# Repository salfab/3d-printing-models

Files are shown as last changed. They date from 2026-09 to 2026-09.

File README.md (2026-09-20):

# 3d-printing-models

Pièces paramétriques modélisées en [OpenSCAD](https://openscad.org/), destinées à
l'impression 3D. Un modèle par sous-répertoire, avec son outillage de rendu, de coupe et
de dessin technique.

Unités : millimètres. Documentation en français.

**[Méthode de conception](WORKFLOW.md)** — le cycle de travail, la discipline de
vérification et les pièges rencontrés, avec leurs chiffres.

**[Journal de conception](work-log/)** — les sessions racontées, ce qu'on y a appris et
ce qu'on y a raté.

## Modèles

| Modèle | Description |
|---|---|
| [rack-sodastream](models/rack-sodastream/) | Rack à visser sous une planche pour deux cylindres de CO2 SodaStream, tenus à l'horizontale et invisibles depuis le dessus |

## Démarrer

Il faut OpenSCAD et Python 3.11 ou plus.

```bash
winget install OpenSCAD.OpenSCAD
```

```bash
python scripts/setup_libs.py
```

Le second installe les bibliothèques OpenSCAD tierces dans `vendor/`, qui est exclu du
dépôt.

## Outillage

`scripts/scad.py` pilote OpenSCAD : il gère les caméras, les fichiers d'enrobage et les
sorties, qui atterrissent toutes dans `models/<slug>/out/`.

```bash
python scripts/scad.py views   <slug>                    # rendus 3D : iso, face, droite, dessus
python scripts/scad.py section <slug> --axis x --at 0    # coupe en demi-espace
python scripts/scad.py slices  <slug> --axis z --count 5 # tranches 2D
python scripts/scad.py drawing <slug>                    # dessins techniques (SVG + PNG)
python scripts/scad.py info    <slug>                    # encombrement, lu dans le maillage
python scripts/scad.py stl     <slug> --binaire          # export STL
```

`--fast` bascule en aperçu au lieu du rendu complet : quelques dixièmes de seconde au
lieu de plusieurs minutes, pour itérer sur la forme.

`info` et les commandes de tranche lisent le **maillage exporté**, pas le source. Les
cotes rapportées sont donc celles qui partiront à l'impression, polygonisation comprise.

## Structure

```
models/<slug>/
  <slug>.scad     fichier principal, exposant un module main()
  README.md       à quoi sert la pièce, cotes, montage, impression
  out/            tout le généré — régénérable, hors dépôt
lib/std.scad      coupes, tranches, vues techniques
scripts/          outillage
vendor/           bibliothèques tierces — hors dépôt
```

Chaque modèle expose un `module main()` et l'appelle : l'outillage fait `use <…>` sur le
fichier, et les rendus, coupes et dessins en dépendent.

## Licence

Aucune licence n'est encore fixée pour ce dépôt. `vendor/BOSL2`, installé séparément,
reste sous sa propre licence BSD-2-Clause.

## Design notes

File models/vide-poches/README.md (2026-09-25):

# vide-poches

Panier mural qui s'enfile par le haut sur deux vis à tête fraisée, en les gardant
invisibles. Fond à deux niveaux reliés par un galbe, crochet à casque sous la partie
haute, inserts amovibles qui bordent l'ouverture d'un liseré — de la couleur qu'on
veut.

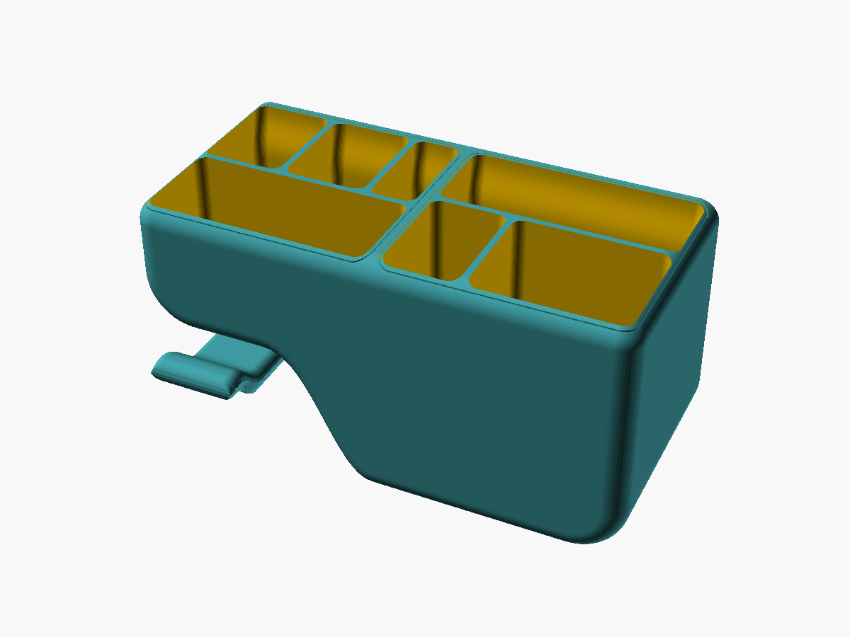
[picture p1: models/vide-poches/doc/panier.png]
Le panier, inserts en place


| Le dos, côté mur | Les inserts, vus de dessus | De profil |
|---|---|---|
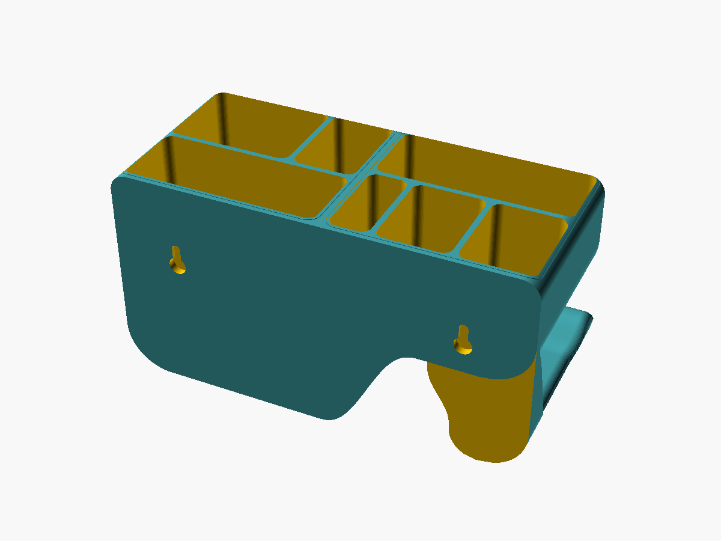
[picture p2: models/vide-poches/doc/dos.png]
Dos et trous de serrure
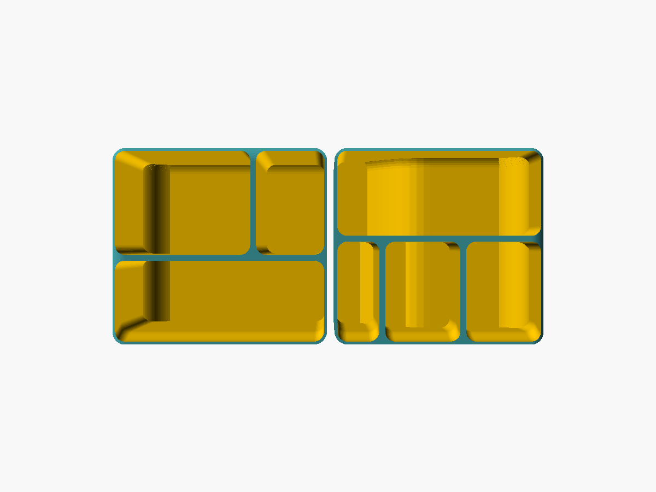
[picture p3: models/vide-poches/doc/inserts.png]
Inserts
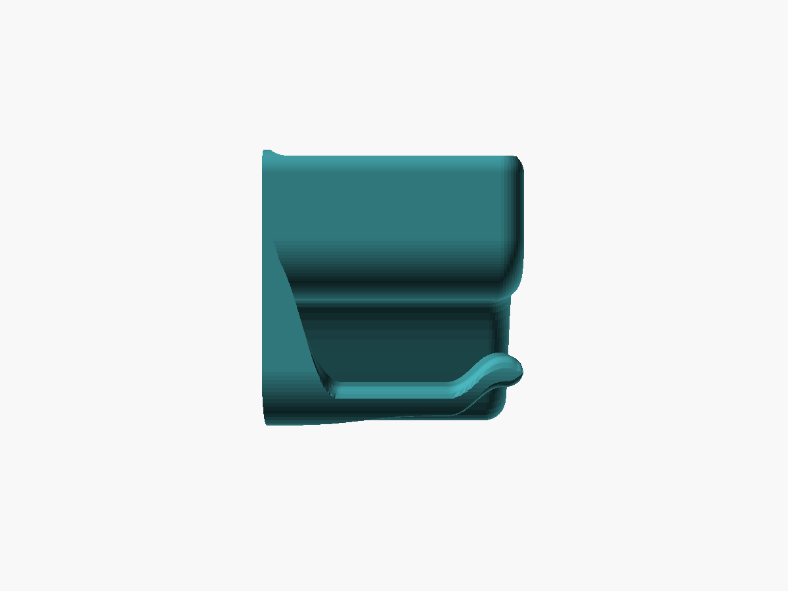
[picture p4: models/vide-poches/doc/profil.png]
Profil et crochet
|  |  |  |
| deux trous de serrure, renflements cachés dans le bac | sept compartiments, deux corps | le crochet prolonge le dessous en S |

### Voir le modèle en 3D

GitHub affiche les fichiers `.stl` dans un **viewer 3D interactif** — clic-glisser pour
tourner, molette pour zoomer, et un bouton pour les télécharger :

- **[Coque](stl/vide-poches-coque.stl)** — 181 × 84,9 × 95 mm
- **[Inserts](stl/vide-poches-insert.stl)** — deux corps, 175,6 × 79,9 × 91,9 mm
- **[Gabarit de pose](stl/vide-poches-gabarit.stl)** — 189 × 28 × 4,8 mm
- **[Pièce d'essai](stl/vide-poches-essai.stl)** — les 10 derniers mm de la coque et des inserts

## 1. À quoi sert la pièce

Vider ses poches en rentrant — paquet de tabac, briquets, lunettes, câbles USB,
petites bricoles — et suspendre dessous un casque **Sony WH-1000XM5**, qui pèse 250 g
et ne se plie pas.

Elle s'accroche sur le flanc d'un meuble en bois, à deux vis **SPAX 3 × 12 à tête
fraisée** posées pour elle, à 124 mm l'une de l'autre. Relevé au pied à coulisse :
tête Ø 6, tige Ø 3, fraisure à 90° (cône de 1,5 mm) ; le petit bord cylindrique
au-dessus est estimé à 0,2.

La forme tient à trois choix :

- **Tout se range debout.** Les lunettes pliées passent de 150 × 46 au sol à 55 × 42,
  la poche à tabac de 105 × 30 à 85 × 30.
- **Le fond est à deux niveaux.** Un bac uniformément profond serait un puits où
  pêcher un briquet : il plonge à gauche (90 mm utiles pour ce qui tient debout) et
  remonte à droite (44 mm pour le vrac), par un galbe et non une marche.
- **Les vis sont invisibles.** La tête entre par un trou au bas de la course ; on
  pousse contre le bois et on descend de 8 mm, et elle se retrouve captive derrière
  une peau de 1,2 mm. Les renflements qui l'entourent sont sous l'arase, derrière
  les inserts.

## 2. Pièces à imprimer

| Pièce | `PIECE=` | Qté | Rôle |
|---|---|---|---|
| Coque | `coque` | 1 | dos, bac à deux niveaux, crochet |
| Inserts | `insert` | 1 jeu | deux petits bacs à séparations, un par zone — **deux corps** dans un même STL |
| Gabarit | `gabarit` | 1 | réglet à trou de serrure, repère de perçage, cale de profondeur — consommable |
| Pièce d'essai | `essai` | 1 | valide le jeu insert / coque **avant tout** |

```bash
python scripts/scad.py stl vide-poches -D PIECE=coque   --binaire
python scripts/scad.py stl vide-poches -D PIECE=insert  --binaire
python scripts/scad.py stl vide-poches -D PIECE=gabarit --binaire
python scripts/scad.py stl vide-poches -D PIECE=essai   --binaire
```

**Deux couleurs de PLA** : les inserts portent le liseré qui borde l'ouverture, et
dessinent dans une autre couleur un filet tout autour du bord, plus les séparations.

Coque et inserts se déduisent de la **même liste `cuves`** : un compartiment ajouté
ou déplacé met tout à jour.

## 3. Cotes principales

Mesurées sur les maillages exportés (moteur Manifold ; `--cgal` rend le même volume
au dixième de cm³).

| Pièce | Volume | Encombrement |
|---|---|---|
| Coque | 184,8 cm³ | 181,0 × 84,9 × 95,0 mm |
| Inserts (2 corps) | 143,0 cm³ (74,2 + 68,8) | 175,6 × 79,9 × 91,9 mm |
| Gabarit | 14,4 cm³ | 189 × 28 × 4,8 mm |

**Compartiments** — cotes utiles, entre parois d'insert :

| Objet | Largeur × profondeur | Hauteur utile | Pourquoi |
|---|---|---|---|
| Poche à tabac, debout | 85,0 × 30,0 | 90 | c'est elle qui fixe la largeur de la zone profonde |
| Lunettes, debout | **55,0** × 41,8 | 90 | à 50, les branches d'une monture large forçaient |
| Stylos, grands objets | 27,6 × 41,8 | 90 | ce qui reste de la zone profonde |
| Briquets, debout | 17,0 × 37,2 | 65 à 76 | Bic J26 et Clipper (16 d'épaisseur) ; replat à 76 |
| Câbles USB | 30,5 × 37,2 | 44 à 47 | replat à 47 : le galbe y montait à 60° contre la paroi |
| Petits objets | 30,5 × 37,2 | 44 | sur le plat |
| Petites bricoles | 82,8 × 34,6 | 44 à 70 | replat à 70 : sans lui, un puits de 90 côté cloison |

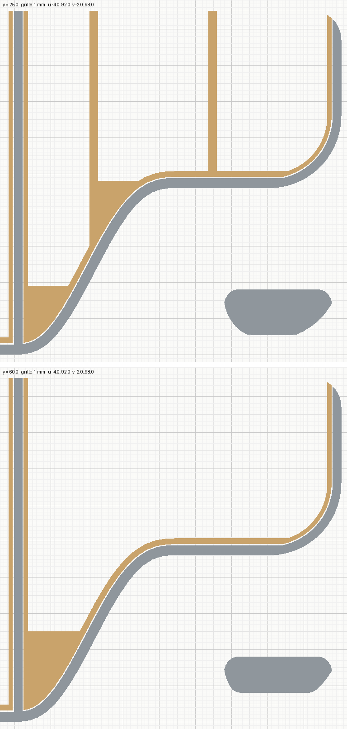
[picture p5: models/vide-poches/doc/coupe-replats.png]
Coupes au droit des câbles et des bricoles


*Coupes en travers, coque en gris, inserts en ocre. En haut au droit des câbles
(y = 25), en bas au droit des bricoles (y = 60) : sous chaque replat, l'insert est
plein jusqu'au galbe, et le compartiment repose sur la coque.*

**Fixation** — de l'arrière vers l'avant, au droit de chaque vis :

```
bois | 1,6 de tige libre | fraisage : 1,0 dans la plaque | 0,4 de cône + 0,2 de bord | 0,4 de jeu | peau 1,2
     └──────────── plaque porteuse 2,6 ────────────┘└───────────── logement 1,0 ─────────────┘
```

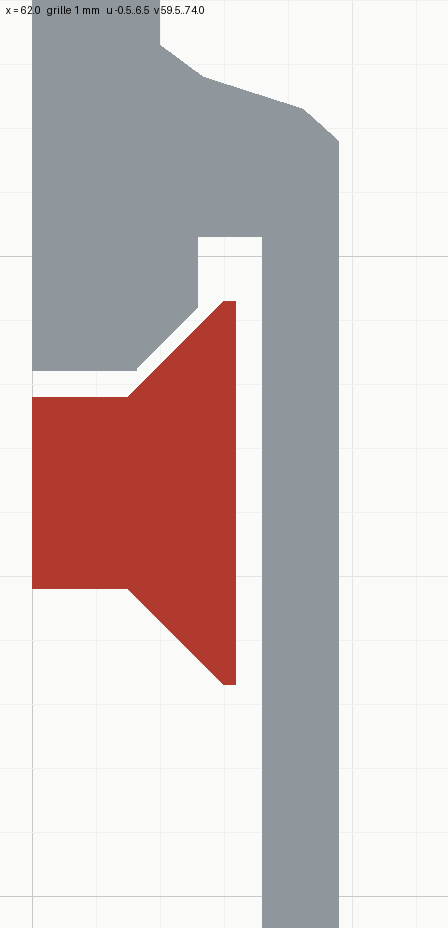
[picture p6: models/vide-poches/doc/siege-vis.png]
La vis dans son siège, en coupe


*Coupe dans l'axe d'une vis (rouge) : la plaque porteuse est fraisée au cône de la
tête, avec 0,3 mm de jeu au rayon.*

| Cote | Valeur | Pourquoi |
|---|---|---|
| Dos, hors fixation | 2,0 mm | `dos_ep` — plein, le trancheur fait l'allègement |
| Dos au droit des vis | 4,8 mm | `dos_e` = plaque + logement + peau |
| Plaque porteuse | 2,6 mm | elle mord 1,0 mm dans le cône : la tête porte sur 19 mm² et s'y centre |
| Jeu au fraisage | 0,3 mm | `jeu_cone` — au rayon, donc aussi en axial à 45° ; 0,4 avec la cale de 1,8 |
| Peau avant | 1,2 mm | `dos_av` — trois passes de buse, elle ne porte rien |
| Course d'enfilage | 8 mm | `course` = rayon du trou d'entrée + rayon de la tête + 1 mm d'appui |
| Trou d'entrée / logement | Ø 7,5 / Ø 8,0 | le logement doit rester **plus large** que le trou qu'il prolonge |
| Axe des vis | 29 mm sous l'arase | au plus bas : le renflement droit se pose à 2 mm du fond peu profond |
| Entraxe | 124 mm | le renflement s'éteint 18 mm avant la paroi latérale, sans la toucher |

**Bac et inserts :**

| Cote | Valeur | Pourquoi |
|---|---|---|
| Parois / cloison / fond | 2,4 / 2,4 / 2,8 mm | `fond` ≠ `paroi`, sinon deux surfaces confondues (§6) |
| Marche entre les niveaux | 46 mm sur 45 de galbe | S quintique : rayon concave mini 17 mm, contre 7 en cubique |
| Arrondi de la face avant et des angles hauts | 8 mm | les deux rayons égaux, sinon angle vif sur la face avant |
| Jeu insert / coque | 0,3 mm par côté | `insert_jeu` — c'est aussi le filet entre les couleurs ; à valider sur `essai` |
| Paroi d'insert | 1,2 mm | trois périmètres ; elle porte le liseré |
| Paroi arrière d'insert | S de 5,1 à 2,3 mm du mur | passe devant les renflements puis recule : liseré de même largeur partout, 14° au plus fort |

**Crochet :**

| Cote | Valeur | Pourquoi |
|---|---|---|
| Portée | 84 mm | le bout arrive à 0,9 de la face avant |
| Creux de l'arceau | ~50 mm, 33 de fond plat | c'est ce creux qui fait que la sangle s'assoit au lieu de se percher |
| Passage sous la coque | 28 mm | la sangle et son coussin |
| Bras au plus fin | 10 mm | 0,3 MPa sous 250 g, contre ~20 MPa de cohésion entre couches |
| Butée | 10 mm, spatule relevée sur 20 | 43° au plus : imprimable sans support |
| Arrondi des arêtes | 4 mm, dessus et dessous | 40 % de l'épaisseur du bras |

Le crochet vu de face reprend la vague de la coque (flanc droit dans le prolongement,
coin de 20, flanc gauche en S) ; de côté, sa racine part tangente au dessous du panier.

## 4. Montage

L'ordre compte : le gabarit se pose sur la **première** vis, et c'est de là qu'il
reporte la seconde.

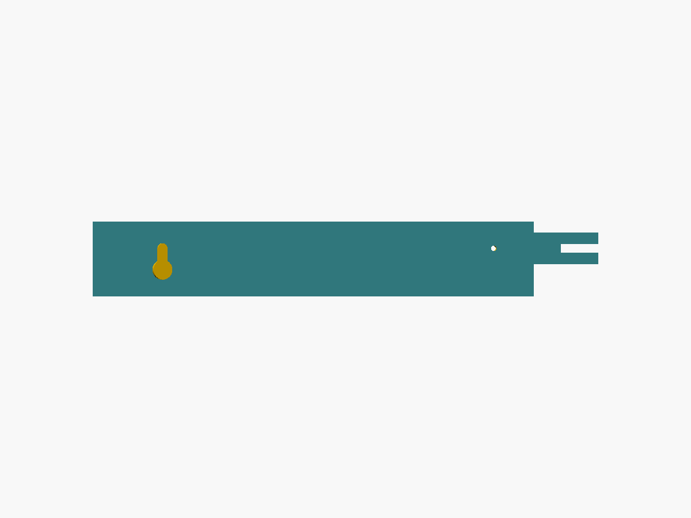
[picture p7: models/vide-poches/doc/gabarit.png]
Le gabarit, vu de dessous


*Le gabarit vu côté mur : à gauche le trou de serrure, identique à celui du panier ;
à droite le repère de Ø 2 et la cale en fourche.*

0. **Imprimer d'abord le gabarit et la pièce d'essai.** L'anneau d'insert doit
   entrer dans l'anneau de coque sans forcer ni ballotter ; sinon, ajuster
   `insert_jeu`.
1. **Poser la première vis** là où le panier doit venir (avant-trou Ø 2 en bois
   tendre, Ø 2,5 en dur). C'est elle qui fixe la hauteur.
2. **Régler sa profondeur à la cale** : glisser la fourche sous la tête, à plat
   contre le bois, et visser jusqu'à ce que le cône en pince les bords. Elle se
   retire en forçant légèrement ; la tige libre fait 1,6 mm.
3. **Enfiler le gabarit** sur cette vis par son trou de serrure : présenter, pousser,
   descendre de 8 mm. Il doit être **captif**. S'il force, la vis est trop profonde ;
   s'il flotte, pas assez. **Si le gabarit ne s'enfile pas, le panier non plus.**
4. **Le mettre d'aplomb et marquer** à travers le repère. Rien sur la pièce ne
   garantit l'horizontale : un petit niveau, ou une mesure égale depuis le chant du
   meuble. Deux vis à des hauteurs différentes font vriller le panier.
5. **Percer, visser la seconde vis**, et la régler à la même cale.
6. **Présenter la coque** les têtes en face des trous d'entrée, **pousser** contre
   le bois, **descendre de 8 mm** : elle vient en butée seule.
7. **Poser les deux inserts**, chacun dans sa zone, à la verticale.

Pour décrocher : remonter de 8 mm, tirer vers soi.

## 5. Impression

- **Coque couchée sur son dos.** La direction de construction est la profondeur : la
  silhouette de la façade sort sans support, et toute surface tournée vers l'avant
  est un toit qui se pose sur la couche du dessous. Seul l'arrière est contraint, et
  il est plat.
- **Inserts à plat, fond contre le plateau.** Seul support du projet : sous le fond de
  l'insert peu profond, qui suit le galbe (~40 g, face cachée).
- **Gabarit à plat**, dans la même orientation que la coque : le pontage de sa peau
  est représentatif de celui du panier.
- **PLA**, remplissage libre : aucune cavité fermée dans aucune pièce.
- Emprise : 181 × 95 mm pour la coque ; 181 × 176 pour la pièce d'essai.

## 6. Contraintes à connaître avant de modifier

**Fixation**

- **Le fraisage ne tolère l'erreur que dans un sens.** Vis trop profonde : la plaque
  ne passe plus. Pas assez : un peu plus de jeu. D'où la cale de **1,8** et non 1,7 —
  1,7 n'est pas un multiple de la couche de 0,2, et le cône écrase le PLA en pinçant ;
  les deux poussent du côté qui coince. Chaque dixième de fourche est un dixième de
  profondeur de vis.
- **Le fraisage doit épouser le cône.** Un chanfrein parallèle mais décalé au rayon
  ne le touche jamais — la tête n'appuie qu'après que le panier a avancé d'autant.
  Vérifier en plaçant la vraie vis dans le canal.
- **`porteur` < fin du cône**, sinon la plaque bute sur le bord cylindrique de la tête.
  Assertion.
- **Le logement de tête reste plus large que le trou d'entrée**, et le fraisage se
  prolonge de 0,3 mm dans le logement : à égalité ou à fleur, les contours coïncident
  (116 arêtes non-variété). Assertions.
- **`z_vis` se déduit du fond, par le bas.** Plus haut, le S de la paroi arrière de
  l'insert se raccourcit ; il faut 10 mm libres au-dessus des renflements. Assertion.
- **Le renflement est ajouté après le creusement du bac**, sinon il disparaît avec lui.
  Il reste sous l'arase (assertion) et au-dessus du fond peu profond (assertion).

**Bac et inserts**

- **Les cavités sont découpées dans l'enveloppe intérieure**, jamais posées à un
  niveau : le dessous remonte vers les coins, et un fond plat y débouchait.
- **Le fond suit le galbe (`plancher`)**, balayé avec le même arrondi avant que
  l'enveloppe intérieure. Extrudé droit, il se confondait avec elle sur tout le galbe.
- **Les replats (briquets, câbles, bricoles) sont pleins dessous.** Creux, le fond de
  1,6 mm pendait au-dessus du vide, tenu par deux côtés.
- **Tous les compartiments au même congé**, et chacun entièrement dans une zone :
  sinon un fragment d'insert se détache, ou le compartiment disparaît.
- **Le dessus des inserts est rogné par la surface extérieure de la coque** : c'est ce
  qui prolonge l'arrondi du bord. Un dessus plat dépasserait.
- **Les coins sont dessinés en plan (`zone_2d`, `r_arr` = 5,7)**, pas laissés au
  balayage, qui les coupait à 44°. Les 0,1 au-delà de 5,6 évitent que le congé naisse
  dans le plan de l'arrondi avant.
- **Le socle du côté peu profond reste plein** : creux, c'était une cavité scellée
  qu'aucun trancheur ne sait soutenir.

**Crochet**

- **Il est l'intersection d'un champ de hauteur (profil de côté) et d'un prisme (vue
  de face)**, et sa racine part 0,3 mm dans la coque pour ne pas lui être tangente.
- **Les congés des arêtes se placent par leur centre**, tangents aux deux faces. Mesurer
  la distance au flanc à plat laissait une marche ; la résoudre par itérations
  oscillait et dessinait des fissures. Au dessus, où l'angle est obtus, le congé finit
  sur le flanc plutôt que de plafonner en bande plate.
- **Le rayon se resserre au bout de la spatule** (demi-épaisseur locale) et s'éteint
  là où le dessus touche encore le panier.
- **Bornes sous assertion** : spatule à 45° au plus (1,875·`croc_r_z` ≤ `croc_gorge`),
  creux ≥ 40 mm, `croc_l` ≤ `prof`, racine et spatule sans chevauchement.

**Coïncidences** — le moteur Manifold transforme en arêtes non-variété ce que CGAL
fusionnait en silence. Règle générale : deux surfaces ne doivent ni se confondre, ni
se toucher tangentiellement, ni partager un plan de départ ; on décale de quelques
centièmes, ou on fait chevaucher franchement.

**Tests permanents**, lancés comme une pièce :

| `PIECE=` | Vérifie | Attendu |
|---|---|---|
| `descente` | que les inserts descendent malgré les renflements | **vide** |
| `peau` | qu'il reste de la matière devant chaque logement de tête | **plein**, 115 mm³ |
| `jointure` | qu'aucun jour ne reste entre le crochet et le dessous de la coque | **vide** |

`scad.py` masque le message « Current top level object is empty » : lancer OpenSCAD
directement pour lire le résultat.

## 7. Points de vérification

- [ ] **Pièce d'essai** : l'insert entre sans forcer ni ballotter (jeu de 0,3).
- [ ] **Cale** : mesurée au pied à coulisse, 1,8 d'épaisseur et 3,4 de fente.
- [ ] **Gabarit enfilé sur une vis réglée** : la tête passe le trou d'entrée, la plaque
      glisse sous le cône, il est captif en haut de course, et la peau de 1,2 est
      sortie propre sur son pontage.
- [ ] **Bord de la tête SPAX** : estimé à 0,2 ; le logement ne laisse que 0,4 de jeu
      devant. Plus haut, remonter `loge_e`.
- [ ] **Paroi arrière en S** : l'insert descend sans frotter, et le S ne marque pas à
      la lumière.
- [ ] **Insert peu profond** : supports faciles à retirer, et il repose sans basculer.
- [ ] **Sangle du XM5** : largeur au réglet (le crochet est dimensionné pour ~38 mm)
      et épaisseur coussin compris, face aux 28 mm de passage.
- [ ] **Tenue des objets debout** : lunettes dans 55 × 42 × 90, blague à tabac dans
      85 × 30.

---

Les images de `doc/` et les STL de `stl/` sont des copies figées des sorties de
`scripts/scad.py`. Après une modification du `.scad`, les régénérer et les recopier :
`scad.py check vide-poches` ne surveille que `out/`.

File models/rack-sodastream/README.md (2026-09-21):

# rack-sodastream

Rack à visser sous une planche en bois pour ranger deux cylindres de CO2
à l'horizontale, invisibles depuis le dessus.

Les cylindres traversent deux plaques percées d'**alésages fermés à 360°** : tenue sur
tout le pourtour, aucun roulement possible. Un rail de guidage relie les deux plaques
pour que le nez du cylindre trouve tout seul le second alésage.

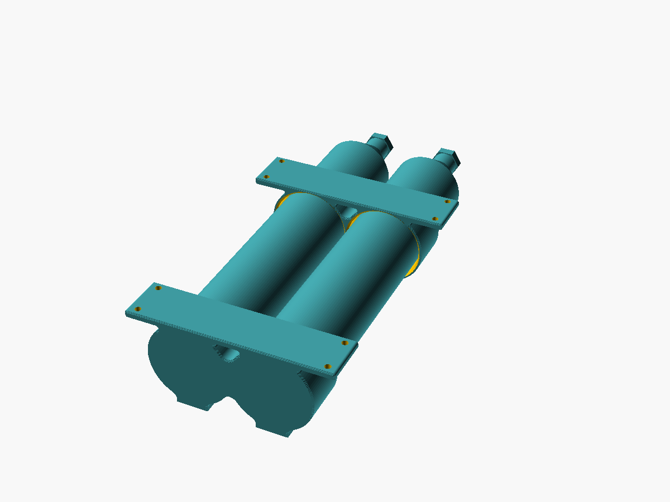
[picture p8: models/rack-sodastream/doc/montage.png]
Rack monté, planche masquée


*L'ensemble en place, planche masquée. Les deux bouteilles ne sont pas imprimées — elles
sont dessinées avec leur robinet pour situer l'encombrement réel.*

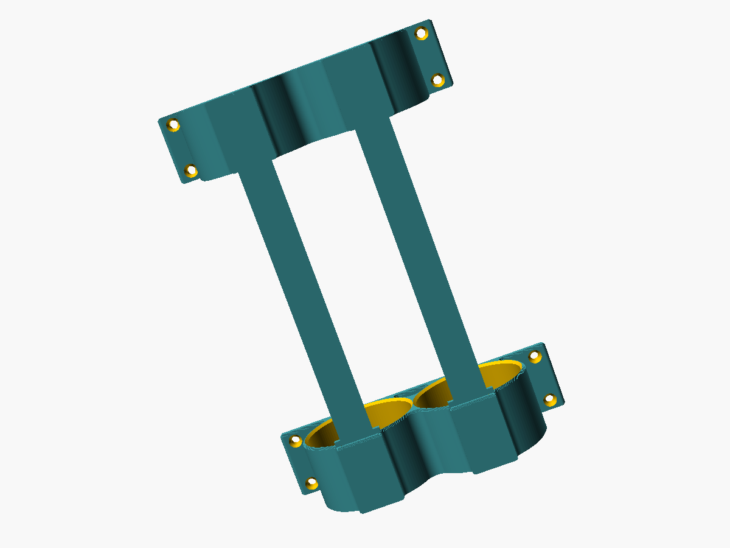
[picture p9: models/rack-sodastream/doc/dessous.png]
Le rack seul, vu de dessous


*Le rack seul, vu de dessous, bouteilles retirées : les deux plaques et les deux rails de
guidage qui les relient. La plaque du fond, en haut, est fermée par sa butée ; celle
d'accès, en bas, laisse voir ses alésages traversants. Ce sont les quatre pièces à
imprimer, et rien d'autre.*

| Plaque avant | Plaque arrière | Rail de guidage |
|---|---|---|
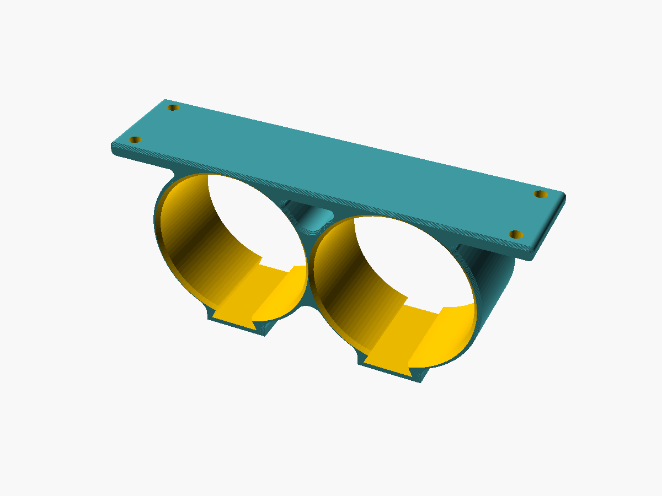
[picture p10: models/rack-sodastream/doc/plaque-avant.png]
Plaque avant
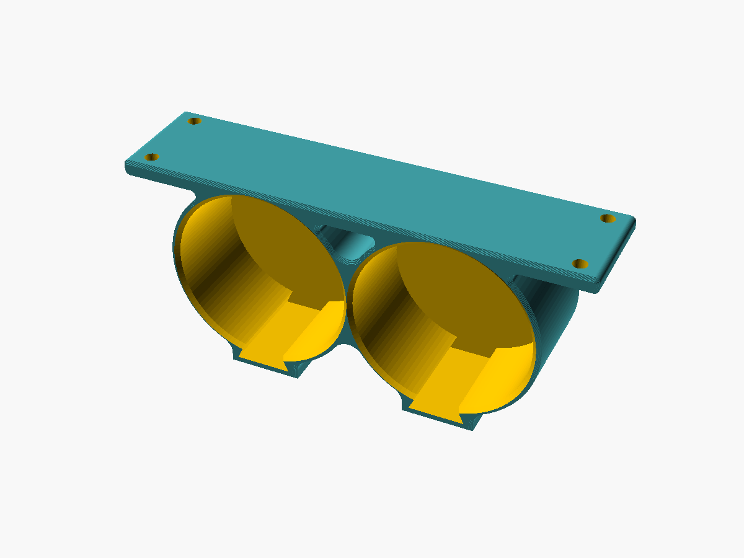
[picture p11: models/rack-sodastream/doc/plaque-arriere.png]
Plaque arrière
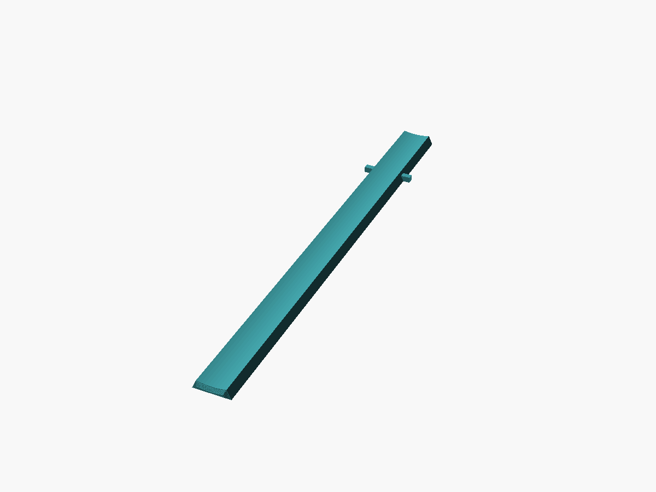
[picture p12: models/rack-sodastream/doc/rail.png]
Rail de guidage
|  |  |  |
| alésages traversants | alésages borgnes, fond de butée | 2 exemplaires |

### Voir le modèle en 3D

GitHub affiche les fichiers `.stl` dans un **viewer 3D interactif** — clic-glisser pour
tourner, molette pour zoomer. Il suffit d'ouvrir l'un de ces fichiers :

- **[Plaque avant](stl/rack-sodastream-avant.stl)** — 167 × 40 × 73,5 mm
- **[Plaque arrière](stl/rack-sodastream-arriere.stl)** — même encombrement, fond de butée plein
- **[Rail de guidage](stl/rack-sodastream-guide.stl)** — 26 × 236 × 4,77 mm

Ces trois fichiers sont des **instantanés versionnés**, exportés du source d'empreinte
`39df96bc`. Les copies de travail vivent dans `out/`, hors dépôt. Pour les régénérer :

```bash
python scripts/scad.py stl rack-sodastream -D PIECE=avant --binaire
```

```bash
python scripts/scad.py check rack-sodastream
```

## Cylindre visé

**Cylindres universels** 425 g / 60 L, filetage TR21×4 : **Ø 60 mm × 356 mm**, 0,72 kg à
vide, ~1,15 kg plein. Pas les cylindres de marque — les universels se rechargent chez
n'importe quel distributeur de gaz.

L'appareil, ici, est une gazéifieuse **Aarke**, qui accepte ce filetage. Le choix de ne
pas passer par du matériel SodaStream est celui de l'auteur, pour des raisons
géopolitiques.

> Le répertoire s'appelle `rack-sodastream` parce que c'est sous ce nom qu'on cherche ce
> genre de pièce. Le modèle, lui, ne dépend que du Ø 60 et du filetage TR21×4.

**Le Ø 60 est mesuré au pied à coulisse**, pas relevé sur une fiche produit — les fiches
se contredisent d'un vendeur à l'autre. La longueur de 356 mm, elle, vient encore d'une
fiche, mais elle ne conditionne aucune cote des pièces imprimées : seulement la
visualisation du montage et le débord du cylindre devant la plaque avant.

Pour un cylindre SodaStream d'origine (plus court et plus gros), changer
`cyl_diametre` et `cyl_longueur` en tête du `.scad` — alésage, entraxe, largeur des
plaques et rail suivent.

## Pièces à imprimer

| Pièce | `PIECE=` | Quantité |
|---|---|---|
| Plaque avant (ouverte) | `avant` | 1 |
| Plaque arrière (fond de butée) | `arriere` | 1 |
| Rail de guidage | `guide` | 2 |

```bash
python scripts/scad.py stl rack-sodastream -D PIECE=avant --binaire
```

```bash
python scripts/scad.py stl rack-sodastream -D PIECE=arriere --binaire
```

```bash
python scripts/scad.py stl rack-sodastream -D PIECE=guide --binaire
```

## Cotes principales

| | |
|---|---|
| Alésage | Ø 63 mm (Ø 60 + 1,5 mm de jeu au rayon) |
| Paroi du collier | 3 mm |
| Profondeur de la plaque | 40 mm, bride et colliers confondus |
| Entraxe des cylindres | 66 mm — les cercles extérieurs se recoupent, âme partagée de 3 mm |
| Encombrement d'une plaque | 167 × 40 mm |
| Hauteur sous la planche | 73,5 mm |
| Écart entre les deux plaques | 200 mm (`ecart_plaques`) |
| Rail de guidage | 236 mm, 20 mm en fond, 15 mm au débouché, 4,77 mm d'épaisseur |

Bride et colliers ont la même profondeur : la plaque est **une seule extrusion
prismatique**, ce qui donne du volume aux colliers et raidit l'ensemble.

## Perçage de la planche

**Quatre vis par plaque, M4 à tête fraisée**, dans les oreilles latérales. C'est le seul
endroit possible : partout ailleurs la tête serait noyée dans la matière des colliers.
Coordonnées en mm, origine au centre de la plaque, X en largeur et Y le long des
cylindres :

```
(-75,5 ; -14)   (+75,5 ; -14)
(-75,5 ; +14)   (+75,5 ; +14)
```

| | mesuré sur le maillage |
|---|---|
| Trou de passage | Ø 5,000 mm nominal, **4,991 mm** au polygone inscrit |
| Fraisage | Ø 8,000 mm, cône à **90,0°**, profondeur **1,50 mm** |
| Matière restante sous le fraisage | 4,5 mm sur les 6 mm de bride |

Une tête fraisée M4 fait 7,5 mm au maximum (DIN 965), pour 2,2 mm de hauteur. Le
fraisage de 8 mm est donc plus large qu'elle : la tête s'enfonce de 0,25 mm sous la
surface au lieu de dépasser. Et le passage de 5 mm laisse 1 mm de flottement au
diamètre sur la tige de Ø 4.

**Visserie retenue : vis à bois Ø 4 à tête fraisée**, vissées directement dans la
planche. Avant-trou Ø 2,5 mm. Le trou de passage de 5 mm et le fraisage de 8 mm leur
conviennent tels quels — ils ont été cotés pour une tête fraisée M4, dont le Ø 7,5 mm
est celui d'une tête de vis à bois Ø 4.

Longueur : l'épaisseur de la bride est de 6 mm, dont 1,5 consommés par le fraisage. Une
vis de 25 mm laisse donc ~20 mm d'ancrage dans le bois.

Les deux plaques sont espacées de 200 mm centre à centre.

Quatre vis sur 151 mm d'entraxe tiennent mieux au basculement que six vis resserrées,
et la charge totale reste de 2,3 kg pour huit vis.

## Le rail de guidage est en queue d'aronde

L'encoche s'évase vers le bas : **20 mm en fond, 15 mm au débouché dans l'alésage**. Le
rail, copie du profil réduite de 0,3 mm, y est donc captif en hauteur comme
latéralement — pour s'échapper vers l'alésage il devrait franchir une ouverture de 15 mm
en étant large de 19. Il ne peut que coulisser axialement, ce que la butée du fond et le
talon d'arrêt bloquent.

Un simple logement ouvert ne tiendrait pas : rien n'empêcherait le rail de se soulever et
de taper contre le cylindre. Un tunnel entièrement fermé aurait tenu le rail, mais
l'aurait séparé de l'alésage par de la matière, et son dessus n'aurait plus prolongé la
surface de guidage.

Dans l'orientation d'impression, les flancs de l'aronde sont verticaux des deux côtés :
aucun porte-à-faux, ni sur la plaque ni sur le rail.

**Jeu de montage : 0,3 mm perpendiculaire**, mesuré sur le maillage — section pleine de
19,06 mm dans une encoche de 20,00, fond du rail à 0,30 mm du fond de l'encoche. Le bout
porte un **chanfrein d'engagement de 1,5 mm** qui l'amincit jusqu'à 14,37 mm.

Ce jeu serré suppose l'ordre de montage ci-dessous. Il tient parce que le rail aligne
lui-même les deux plaques *avant* qu'elles ne soient vissées.

**Le rail est aussi raccourci de 1 mm** (`guide_jeu_axe`). Sans ce retrait il ferait
exactement les 237 mm disponibles entre le fond de butée et la face avant, et les seules
tolérances d'impression suffiraient à l'empêcher d'entrer.

**Le talon d'arrêt** est une collerette large de 26 mm, **reculée de 40 mm** depuis le
bout avant — soit exactement la profondeur d'une plaque. Plus large que l'encoche, qui
n'en fait que 20, elle ne peut pas la traverser : elle porte contre la face *arrière* de
la plaque avant, sur environ 4 mm de chaque côté. C'est l'**avancée** du rail qu'elle
arrête, la seule direction par laquelle il pourrait sortir ; le recul est déjà pris par
la butée du fond.

Elle s'évase **latéralement**, à partir du même fond plat que le rail, et ne descend pas
en dessous. Un talon qui descendrait aurait obligé à imprimer les 236 mm du rail sur
support.

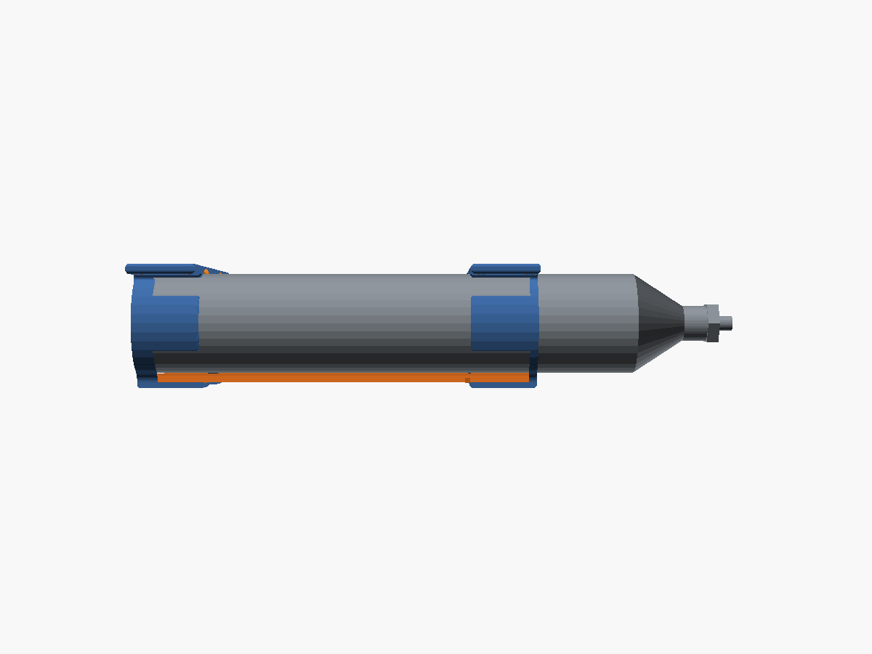
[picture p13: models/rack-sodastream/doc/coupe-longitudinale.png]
Coupe dans l'axe du cylindre


*Coupe longitudinale du montage, dans l'axe d'un cylindre. Le rail court sous la
bouteille d'une plaque à l'autre ; le talon est la petite patte qui remonte juste
derrière la plaque d'accès.*

Un talon placé au bout du rail, en appui sur la face *avant*, n'aurait rien bloqué
d'utile : il n'aurait arrêté que le recul, déjà limité à 1 mm par la butée, en laissant
le rail libre de coulisser vers l'avant et de tomber.

Conséquence sur le montage : le talon ne peut pas franchir l'encoche, donc **le rail
s'introduit par l'arrière**, avant la pose de la plaque du fond. En contrepartie, rien
ne dépasse de l'encombrement du rack.

Le jeu ne peut pas faire dépasser le rail dans l'alésage : comme il est uniforme, le
rail qui remonte au maximum arrive exactement affleurant, jamais au-delà — les lèvres
l'arrêtent là.

## Montage

L'ordre compte : **assembler d'abord, percer ensuite.**

1. Enfiler les deux rails dans la plaque avant **par l'arrière**, jusqu'à ce que leur
   talon vienne buter sur la face arrière de la plaque ; le bout du rail affleure alors
   la face avant. Engager ensuite la plaque du fond sur l'autre extrémité des rails.
   Le rack tient alors tout seul, et les rails imposent l'alignement des deux plaques.
2. Présenter le rack assemblé sous la planche, butée côté fond, et **marquer les huit
   avant-trous à travers les oreilles**. Ne pas percer d'après un gabarit théorique.
3. Démonter, percer les avant-trous Ø 3 mm, visser les deux plaques, puis remonter les
   rails — plaque du fond en dernier.
4. Engager les cylindres. Ils butent contre le fond de la plaque arrière et dépassent
   d'environ 116 mm devant la plaque avant — de quoi les saisir.

**Pourquoi marquer plutôt que mesurer.** Les vis sont à tête fraisée : le cône à 90° se
centre dans son fraisage en se serrant et annule les 0,25 mm de flottement des trous de
passage. Ce sont donc les avant-trous, et non le rail, qui fixent la position des
plaques. Percés d'après un gabarit, ils désaligneraient les deux arondes et le rail
coincerait. Marqués à travers le rack monté, ils sont justes par construction.

## Impression

- **Plaques** : posées à plat, alésages verticaux. Aucun support. Les couches sont alors
  perpendiculaires à l'axe des cylindres, donc la charge ne travaille pas en pelage.
- **Plaque arrière** : butée côté plateau, pour éviter un pontage sur Ø 63.
- **Rails** : posés sur leur fond plat, creux vers le haut. Aucun support : toute la
  face inférieure touche le plateau, talon compris, et rien ne dépasse par en dessous.
- PLA ou PETG, 3 périmètres, 25 % de remplissage. La paroi de 3 mm est entièrement
  remplie par les périmètres.

## Contraintes à connaître avant de modifier

- **La bride ne fait que 1,5 mm d'épaisseur au-dessus de chaque alésage.** Le chanfrein
  d'entrée, de rayon 33 mm, y remonte jusqu'à −1,5 mm alors que la bride s'étend de 0 à
  −6. C'est la section la plus fine de la plaque. Elle ne reprend aucun effort — la
  charge descend par les colliers — mais toute augmentation de `chanfrein` la réduit
  encore.
- **`ecart_plaques` ne peut pas dépasser ~213 mm** sur un plateau de 256 mm : la longueur
  du rail vaut `ecart_plaques + 40 − 3`, et au-delà il faudrait l'imprimer en diagonale
  ou le couper en deux.
- **`coin` ne peut pas dépasser `bride_ep / 2`**, sinon le carré de base de la bride
  devient de hauteur négative et la bride disparaît sans erreur. Le modèle borne
  désormais la valeur, mais la contrainte reste réelle.
- **Le chanfrein d'entrée des alésages ne peut pas dépasser `paroi − 1`** : au-delà, le
  cône de chanfrein mange toute l'épaisseur du collier à la face d'entrée.
- Le chanfrein des arêtes d'extrémité est un empilement de marches, faute d'opérateur de
  chanfrein 3D en OpenSCAD standard sur un profil aussi concave. Réglé à 0,2 mm par
  marche, soit une couche d'impression : le trancheur produit le même résultat qu'avec un
  vrai chanfrein à 45°.

## Points de vérification

- Le Ø du cylindre est **confirmé à 60 mm au pied à coulisse**. Le jeu de 1,5 mm au rayon
  donne donc 2,978 mm de battement diamétral réel — mesuré sur le maillage, polygonisation
  comprise. Franc à glisser ; pour un maintien plus serré, passer `jeu_radial` à 0,75.
- Le rail affleure 0,3 mm sous la surface de l'alésage : il ne serre jamais le cylindre,
  il ne fait que rattraper le nez quand il pique.
- Si le rail coulisse trop dur une fois les plaques vissées, c'est le perçage qui est en
  cause avant le modèle. Avant d'augmenter `guide_jeu`, vérifie qu'il coulisse bien sur
  les plaques libres : si oui, ce sont les avant-trous qui tirent les plaques de travers.

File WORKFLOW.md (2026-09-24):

# Méthode de conception

Comment on conçoit une pièce dans ce dépôt : le cycle de travail, l'outillage, et la
discipline de vérification qui va avec.

Ce document s'adresse aux humains. [`CLAUDE.md`](CLAUDE.md) contient les mêmes
conventions sous forme d'instructions pour Claude Code — les deux doivent rester
cohérents.

## 1. Le cycle

```
cadrer  →  paramétrer  →  rendre vite  →  REGARDER  →  mesurer  →  itérer
                              ↑                                      │
                              └──────────────────────────────────────┘
```

**Cadrer d'abord.** Une pièce imprimée matérialise une série de décisions : diamètre
réel de l'objet à accueillir, jeu fonctionnel, sens d'insertion, orientation
d'impression, mode de fixation. Les arrêter avant de modéliser coûte cinq minutes ;
les découvrir après coûte une bobine.

**Paramétrer, pas coter.** Toute dimension est une variable nommée en tête de fichier,
avec son unité et la raison de sa valeur. Un modèle où l'on change le diamètre de
l'objet visé et où tout suit vaut infiniment mieux qu'un modèle juste une fois.

**Rendre vite pour itérer.** `--fast` produit un aperçu en quelques dixièmes de
seconde. Le rendu complet, avec le moteur Manifold, ne prend plus que quelques
secondes par pièce — il en fallait plusieurs minutes avec CGAL : on peut désormais
itérer sur le rendu complet, qui seul montre ce que les booléens produisent vraiment.

**Regarder.** C'est l'étape qu'on saute et qu'il ne faut jamais sauter. Un rendu qu'on
n'a pas ouvert ne prouve rien. Deux exemples vécus : une bride entièrement disparue
d'un modèle qui compilait sans la moindre erreur, et des colliers si étroits qu'ils ne
lisaient plus comme des volumes.

**Mesurer sur le maillage, pas sur le source.** Le `.scad` dit ce qu'on a demandé ; le
STL dit ce qui sera imprimé. Entre les deux il y a la polygonisation, les opérations
booléennes et les approximations de CGAL. `scripts/scad.py info` et les scripts d'analyse
lisent le maillage exporté.

## 2. L'outillage

| Outil | Rôle |
|---|---|
| `scripts/scad.py` | pilote OpenSCAD : rendus, coupes, tranches, dessins, STL, encombrement, contrôle de péremption |
| `lib/std.scad` | `section()`, `quarter_cut()`, `slice_2d()`, `view_2d()`, et la résolution des courbes |
| `scripts/setup_libs.py` | installe les bibliothèques tierces et OpenSCAD de développement dans `vendor/`, exclu du dépôt |
| skill `scad-preview` | publie un aperçu web : viewer 3D interactif et planche de rendus |

Passer par `scad.py` plutôt que par `openscad` en direct : les caméras normalisées et
l'enrobage `use <>` qui permet de couper ou projeter un modèle sans le modifier sont
non triviaux, et le contrôle de péremption ne fonctionne que par lui.

```bash
python scripts/scad.py views   <slug> --fast          # itérer sur la forme
python scripts/scad.py section <slug> --axis quarter  # voir l'intérieur
python scripts/scad.py slices  <slug> --axis z --count 5
python scripts/scad.py drawing <slug>                 # dessins techniques cotables
python scripts/scad.py info    <slug>                 # encombrement mesuré
python scripts/scad.py stl     <slug> --binaire
python scripts/scad.py check   <slug>                 # les sorties sont-elles à jour ?
python scripts/scad.py stl     <slug> --cgal          # contre-vérification, ancien moteur
```

**Le moteur : Manifold par défaut, CGAL en contre-vérification.** Sur le vide-poches,
la coque s'exporte en 5 s au lieu de 2 min 30, et la régénération complète de
l'aperçu tombe de plus d'une demi-heure à 4 minutes. Les deux moteurs rendent le
même volume au dixième de cm³ près. Ils ne tranchent pas pareil les cas limites :

- **Manifold ne recolle pas deux corps qui se touchent par une face.** CGAL, en
  arithmétique exacte, fusionnait la plaque et le bac, extrudés bout à bout sur le
  même contour ; Manifold y a laissé 129 arêtes pincées. Idem pour un encorbellement
  dont le pied se couchait sur la face d'une paroi : 8 arêtes. Chaque fois, le
  remède est celui de toutes les coïncidences — un seul corps, ou un recouvrement
  franc — et il rend le modèle plus sain pour les deux moteurs.
- **`use <>` n'importe pas les variables globales**, et BOSL2 en initialise
  (`$tags_shown`…). La 2021.01 laissait passer ; les versions récentes refusent. Les
  enrobages de `scad.py` incluent donc BOSL2 eux-mêmes quand le modèle s'en sert.
- **Valider sur le moteur qui produit le STL.** Tests permanents et contrôles de
  maillage n'ont de sens que sur le fichier qui part à l'imprimante.

`-D CLE=VALEUR` surcharge n'importe quelle variable du modèle. C'est ainsi qu'un même
fichier produit plusieurs pièces — `-D PIECE=avant`, `-D PIECE=guide` — sans duplication,
et les sorties sont nommées d'après la variante.

## 3. Quatre vérifications, pas une

Une pièce peut être juste sur un axe et fausse sur un autre. Chacun de ces quatre
contrôles a rattrapé un défaut réel dans ce dépôt, qu'aucun des trois autres ne voyait.

**Les sections.** Épaisseurs de paroi, jeux, matière restante aux emboîtements. Se
mesure sur le maillage. Attention au piège du diamètre : OpenSCAD trace des polygones
**inscrits**, donc un alésage passe toujours un peu plus petit que sa cote nominale.
C'est la distance du centre au **milieu de chaque corde** qui donne le passage réel —
un contrôle naïf sur les sommets afficherait la cote nominale et masquerait le défaut.

**La cinématique.** *Dans quel sens cette pièce peut-elle bouger, et qu'est-ce qui l'en
empêche ?* Un arrêt peut être parfaitement dimensionné et bloquer la mauvaise direction.
Les sections ne le voient jamais.

**L'imprimabilité.** Porte-à-faux, pontages, orientation des couches vis-à-vis de la
charge. **À revérifier après toute modification de géométrie** : un changement de forme
peut invalider une contrainte de fabrication établie plus tôt, et c'est une régression
qu'aucune mesure de section ne détecte.

**La fraîcheur.** Les sorties viennent-elles bien du source actuel ? Une génération
lancée en tâche de fond continue pendant qu'on modifie le `.scad`, et les rendus se
retrouvent issus de versions différentes sans que rien ne le signale.

```bash
python scripts/scad.py check <slug>
```

Chaque sortie est inscrite dans `out/.manifest.json` avec l'empreinte SHA-256 des
sources dont elle vient — le `.scad` du modèle **et** `lib/`, puisqu'un module partagé
périme aussi les rendus. `preview_pack.py` refuse de publier tant qu'une sortie est
périmée.

## 4. Pièges rencontrés

Tous vérifiés dans ce dépôt, avec leurs chiffres.

**Un `offset(r=)` trop grand vide une forme en silence.** Arrondir les coins d'une bride
de 6 mm avec un rayon de 4 donne un carré de base de hauteur −2 : profil vide, aucune
erreur, bride absente du rendu. Borner les rayons par construction.

**Une résolution trop fine fait exploser le temps de calcul.** `$fa = 1` produit 360
segments sur un alésage de Ø 69 et portait un rendu à plus de sept minutes. À `$fa = 3`,
soit 120 segments, la flèche tombe à 0,011 mm — très en deçà de ce qu'une buse de 0,4 mm
reproduit — et le rendu à moins de deux minutes.

**OpenSCAD 2021.01 n'exporte qu'en STL ASCII**, six fois plus volumineux que le binaire.
D'où l'option `--binaire`, qui ramène une plaque de 9,3 à 2,6 Mo.

**Comparer deux fichiers n'est pas comparer deux pièces.** Un `cmp` opposant un export
binaire à un export ASCII crie « différent » sur une géométrie rigoureusement identique.
Comparer plutôt le nombre de triangles, de sommets distincts, et l'encombrement.

**Le chanfrein 3D n'existe pas en OpenSCAD standard.** Sur un profil concave, ni `hull()`
— qui rend l'enveloppe convexe — ni `minkowski()` — impraticable au-delà de quelques
centaines de sommets — ne conviennent. Deux sorties : empiler des tranches de profil
décalé à raison d'une marche par couche d'impression, ou passer par BOSL2 et
`offset_sweep()`.

**Le rendu couleur d'OpenSCAD 2021.01 n'est pas fiable.** `color()` est ignoré par le
rendu CGAL ; il ne s'affiche qu'en aperçu OpenCSG, qui produit des traînées blanches
ressemblant à des trous là où deux surfaces sont proches ou minces. Une illustration
montrant plusieurs pièces doit donc les distinguer **par la forme ou par la séparation**,
jamais par la couleur : dessiner un détail reconnaissable, ou simplement retirer de la
scène ce qui n'est pas le sujet. Le corollaire vaut aussi pour le diagnostic : un trou vu
sur un aperçu se vérifie sur le maillage avant d'être cru.

**Une pièce obtenue par soustraction peut sortir en plusieurs morceaux.** Quand on
définit un objet comme « le plein moins les creux » — des séparateurs comme
l'intérieur moins les compartiments, par exemple — il suffit qu'un creux soit plus
arrondi que son voisin pour qu'il reste dans un coin un fragment détaché du reste,
que rien ne signale. Le contrôle se fait sur le maillage : on soude les sommets par
position, on relie ceux qui partagent un triangle, et on somme le volume signé de
chaque composante. **Une composante de volume positif est une pièce, une composante
de volume négatif est une cavité fermée.** Deux volumes positifs, c'est un morceau
libre. Le dos du vide-poches, par exemple, compte 1 coque et 14 cavités : correct.

**Une cavité fermée n'est pas un allègement gratuit.** Des poches prises entre deux
peaux se lisent volontiers comme « ouvertes », alors que le trancheur doit ponter
chacune sur tout son pas. Le commentaire qui les décrit doit dire laquelle des deux
choses elles sont, sinon c'est lui qu'on croira.

**Un trou dans un modèle est presque toujours une coïncidence, pas une absence.**
Trois s'en sont suivies sur la même pièce, toutes rendues en arêtes non-variété et
toutes vues à l'écran comme un trou. *Un niveau dérivé qui retombe sur une surface* :
un fond de compartiment à `marche + fond` et un dessous d'enveloppe à `marche + paroi`
sont le même plan tant que `fond == paroi`. *Un prisme de creusement borné pile sur la
paroi qu'il longe* : il doit déborder franchement — 5 mm, pas 0,2, sinon on remplace la
face coplanaire par un éclat rasant. *Deux balayages concentriques à leur lèvre* : un
arrondi `offset_sweep` rentre le profil de son propre rayon, donc un extérieur arrondi
de `r` et un intérieur décalé de `e` et arrondi de `r - e` **coïncident exactement** à
la lèvre ; tout ce qui se soustrait doit s'arrêter avant.

Un quatrième cas, rencontré en refaisant le crochet : **un plan de recoupe qui passe
par un sommet du profil.** Une courbe échantillonnée dont le premier point tombait à
y = 0 pile, recoupée en y = 0, a donné 35 arêtes non-variété d'un coup. Le remède est
le même que partout ailleurs — faire déborder la forme au-delà du plan de coupe, et
ne pas y laisser de sommet.

Le diagnostic qui a marché : compter les arêtes du maillage par nombre de faces, puis
**lister les arêtes non-variété une par une avec leurs coordonnées**. Les histogrammes
par axe ne disent rien ; les coordonnées brutes, elles, tombent pile sur les valeurs
nommées du source — `±xi0`, `dos_ep`, `fond_haut` — et nomment le coupable.

**Le compteur d'arêtes a lui-même une tolérance, et elle peut mentir.** Pour
compter les arêtes on soude les sommets par position arrondie. À 3 décimales, deux
sommets distincts distants de 0,002 mm — là où un profil en S effleure une surface
presque plate — étaient fusionnés, et le compteur annonçait 2 arêtes non-variété
qui n'existaient pas. Relancé à 2, 3, 4, 5 et 6 décimales : 17, 2, 0, 0, 0. Un
compte qui dépend de la tolérance est un artefact ; un vrai défaut persiste à toutes
les précisions. Souder à 5 décimales, et en cas de doute faire varier.

**Zéro arête de bord ne veut pas dire zéro trou.** Une soustraction qui débouche là où
elle ne devrait pas produit une forme parfaitement fermée : le maillage est sain, la
pièce est percée. C'est le volume et les composantes qu'il faut regarder, pas l'étanchéité.

**Un `-D` mal cité échoue en silence.** OpenSCAD rend 0 même quand il n'a rien
écrit : des guillemets passés en trop produisent un nom de fichier invalide, aucun
export, aucune erreur — et la mesure suivante porte sur le fichier de la run
précédente. `scripts/scad.py` refuse désormais un export vide.

**Éditer un fichier par script est dangereux ; passer par un outil d'édition qui
exige une correspondance unique ne l'est pas.** Un `str.index()` sur un marqueur qui
apparaît deux fois dans un fichier a produit une tranche vide, puis un
`replace("")` a inséré un bloc entre chaque caractère : 339 lignes devenues 1,2
million. Corollaire : **commiter un modèle dès qu'il compile**, avant toute
retouche — c'est ce qui rend l'incident réparable au lieu d'être une perte sèche.

**Retoucher un commentaire périme toutes les sorties.** Le manifeste hache le `.scad`
entier : corriger une cote dans un commentaire après les exports les rend tous
périmés, et `check` a raison de le dire — rien ne prouve que seul un commentaire a
changé. Finir les commentaires AVANT de lancer la régénération, surtout quand elle
dure une demi-heure.

**Un test de descente par projection ne vaut que si rien ne surplombe légitimement
l'obstacle.** « Projection de l'insert ∩ projection de l'obstacle = vide » suppose
que l'insert descend jusqu'en bas partout où il a de la matière. Un bandeau qui passe
AU-DESSUS d'un renflement fait échouer ce test à tort. Le bon critère est par
niveaux : pour chaque hauteur zk, ce qui est sous zk dans l'insert contre ce qui est
au-dessus de zk dans l'obstacle.

**Les têtes fraisées annulent le jeu des trous de passage.** Un cône à 90° se centre
dans son fraisage en se serrant. Ce sont donc les avant-trous qui imposent la position
d'une pièce vissée, pas l'ajustement des trous — d'où l'obligation de marquer les
perçages à travers l'assemblage monté plutôt que d'après un gabarit.

## 5. Publier un aperçu

La skill `scad-preview` produit un artefact web à deux onglets : un viewer 3D rotatif
alimenté par le STL, et une planche des rendus, coupes et dessins.

Trois contraintes techniques y sont figées, chacune vérifiée :

- **Un seul script externe**, `three.min.js` en UMD depuis cdnjs. Le dossier `examples/`
  n'y est pas servi — `STLLoader.js` renvoie 404 — donc le parseur de STL binaire et les
  contrôles d'orbite sont écrits en ligne.
- **Le STL ne peut pas être un fichier compagnon** : `model/stl` n'est pas un type web
  standard. Il transite en base64 dans un `.js`. Les PNG, eux, partent en fichiers
  compagnons, là où est le volume.
- **Le cadrage caméra doit tenir compte du champ horizontal**, pas seulement du vertical :
  sur un écran de téléphone, étroit et haut, c'est lui qui contraint.

Tester la page en local avant publication, via le serveur déclaré dans
`.claude/launch.json`, évite de consommer une version d'artefact pour un essai.

## 6. Conventions

- **Un modèle par sous-répertoire** sous `models/<slug>/`, jamais de `.scad` de modèle à
  la racine.
- Le fichier principal **expose un `module main()`** et l'appelle. L'outillage fait
  `use <…>` dessus : sans `main()`, ni rendu, ni coupe, ni dessin.
- **Chaque modèle a un README**, rédigé au fur et à mesure. Ses sections sont décrites
  dans `CLAUDE.md`, et `models/_template/README.md` en donne le squelette.
- Millimètres partout. Documentation en français.
- `models/*/out/` et `vendor/` sont hors dépôt : régénérables l'un et l'autre.

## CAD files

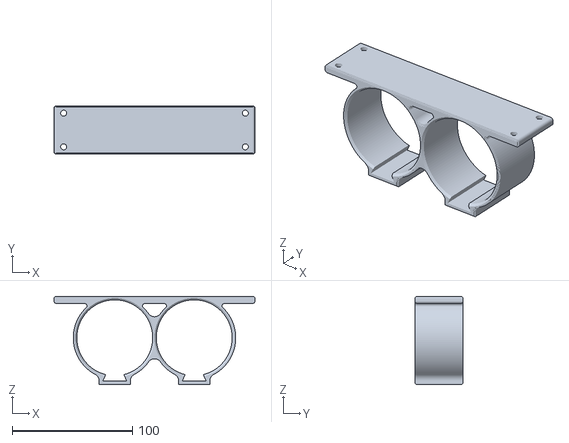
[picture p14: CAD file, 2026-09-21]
models/rack-sodastream/stl/rack-sodastream-avant.stl
167.0 x 40.0 x 73.5

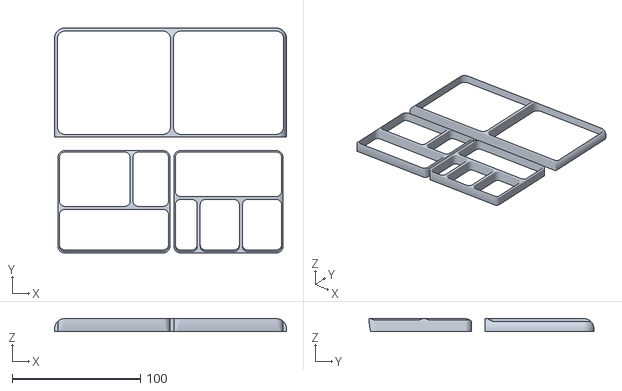
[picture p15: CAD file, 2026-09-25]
models/vide-poches/stl/vide-poches-essai.stl
181.0 x 175.5 x 10.0

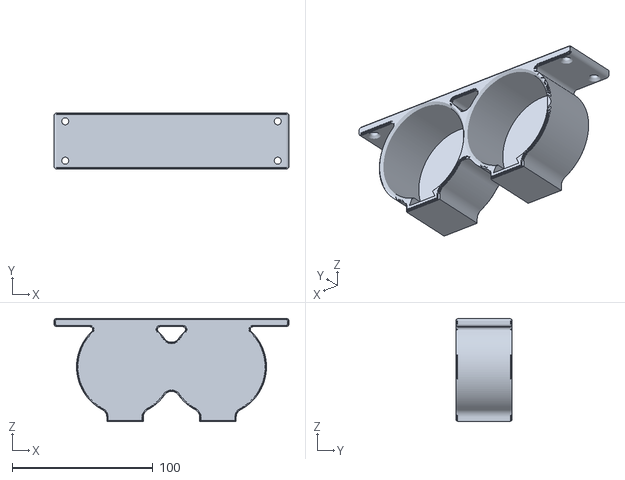
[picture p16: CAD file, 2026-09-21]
models/rack-sodastream/stl/rack-sodastream-arriere.stl
167.0 x 40.0 x 73.5

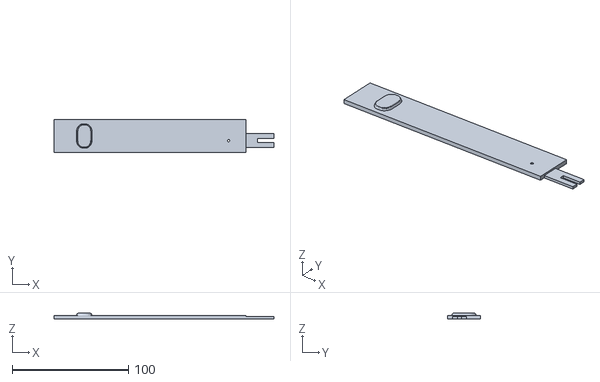
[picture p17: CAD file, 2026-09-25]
models/vide-poches/stl/vide-poches-gabarit.stl
189.0 x 28.0 x 4.80

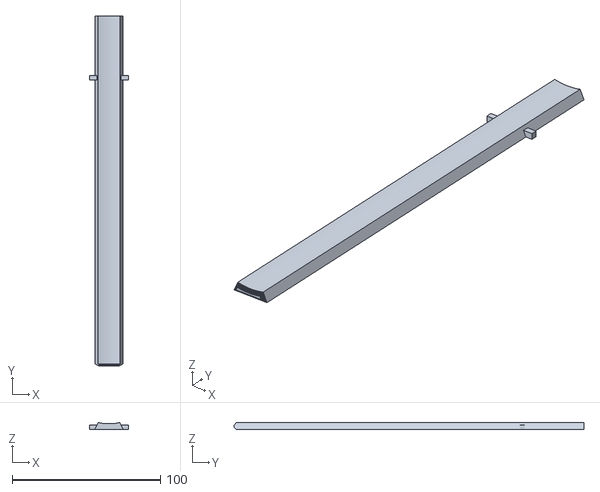
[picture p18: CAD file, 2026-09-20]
models/rack-sodastream/stl/rack-sodastream-guide.stl
26.0 x 236.0 x 4.77

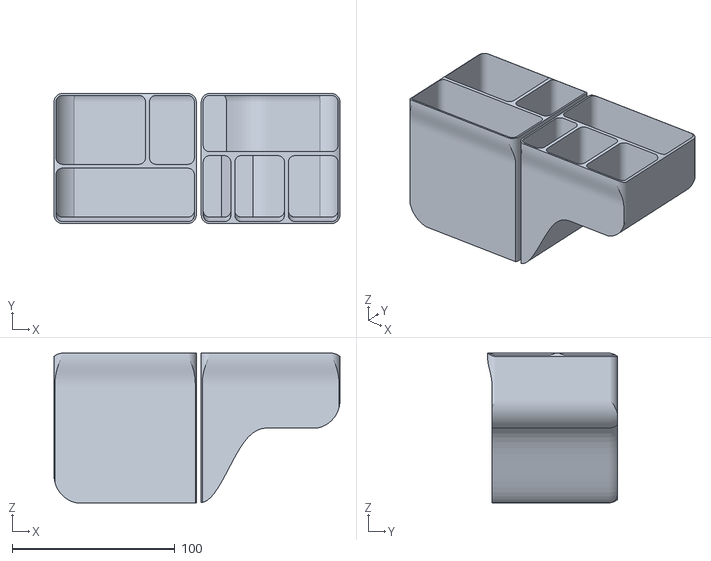
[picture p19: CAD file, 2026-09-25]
models/vide-poches/stl/vide-poches-insert.stl
175.6 x 79.9 x 91.9

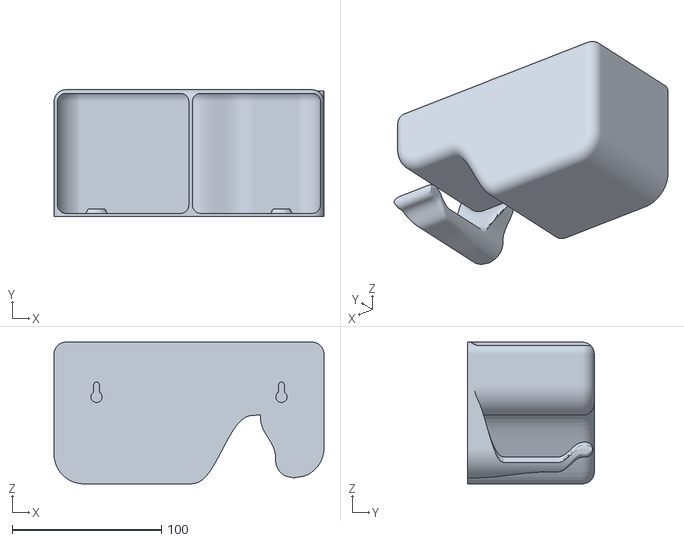
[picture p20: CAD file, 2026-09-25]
models/vide-poches/stl/vide-poches-coque.stl
181.0 x 84.9 x 95.0

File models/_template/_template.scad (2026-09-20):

// _template — point de départ pour un nouveau modèle.
// Copier le répertoire, le renommer <slug>, renommer ce fichier <slug>.scad.

include <../../lib/std.scad>

// --- Paramètres -------------------------------------------------------------

largeur   = 40;   // mm
profondeur = 30;  // mm
hauteur   = 20;   // mm
paroi     = 2.4;  // mm — 3 périmètres à 0.4 mm de buse
jeu       = 0.3;  // mm — jeu fonctionnel des ajustements glissants

// --- Géométrie --------------------------------------------------------------

module main() {
    difference() {
        cube([largeur, profondeur, hauteur], center = true);
        translate([0, 0, paroi])
            cube([largeur - 2 * paroi, profondeur - 2 * paroi, hauteur], center = true);
    }
}

main();

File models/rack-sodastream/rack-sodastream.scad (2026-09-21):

// rack-sodastream — rack à visser sous une planche pour cylindres de CO2 SodaStream.
//
// Deux plaques identiques, percées d'alésages fermés à 360°, espacées le long de
// l'axe des cylindres. Les bouteilles se glissent axialement à travers les deux.
// Aucun demi-cercle : le cylindre est tenu sur tout son pourtour et ne peut pas rouler.
//
// La plaque est une seule extrusion prismatique : bride et colliers ont la même
// profondeur, ce qui donne du volume aux colliers et raidit l'ensemble.
//
// Repère : X = largeur (perpendiculaire aux cylindres)
//          Y = axe des cylindres
//          Z = vertical, z = 0 est la sous-face de la planche, la matière descend.

include <../../lib/std.scad>

// --- Pièce à produire -------------------------------------------------------
// "avant"   : plaque ouverte, côté par lequel on introduit le cylindre
// "arriere" : plaque avec fond de butée
// "guide"   : rail de guidage reliant les deux plaques (à imprimer en 2 exemplaires)
// "montage" : visualisation de l'ensemble monté, cylindres compris (non imprimable)
PIECE = "avant";

// --- Cylindre de gaz --------------------------------------------------------

cyl_diametre = 60;    // mm — Ø du corps (recharge universelle 425 g / TR21x4)
cyl_longueur = 356;   // mm — longueur hors tout, filetage compris
jeu_radial   = 1.5;   // mm — jeu au rayon pour un glissement franc

// --- Plaque -----------------------------------------------------------------

nb_cylindres = 2;
paroi        = 3;     // mm — épaisseur du collier, et de l'âme partagée
plaque_prof  = 40;    // mm — profondeur le long de l'axe, bride et colliers confondus
butee_ep     = 3;     // mm — fond de butée de la plaque arrière

// --- Adoucissement des arêtes -----------------------------------------------

conge        = 6;     // mm — congé aux cuspides entre deux colliers
raccord      = 2;     // mm — congé au raccord bride / colliers
coin         = 2;     // mm — rayon des coins de la bride (max bride_ep/2)
chanfrein    = 1.5;   // mm — chanfrein d'entrée des alésages
chanf_bord   = 1.2;   // mm — chanfrein des arêtes d'extrémité (0 pour aucun)
chanf_pas    = 6;     // marches du chanfrein : 1,2/6 = 0,2 mm, une couche

// --- Rail de guidage --------------------------------------------------------
// Prolonge la surface de l'alésage d'une plaque à l'autre pour que le nez du
// cylindre ne puisse pas manquer le second alésage.

guide         = true; // false pour un rack sans rails
guide_larg    = 20;   // mm — largeur de l'encoche en fond
guide_aronde  = 3;    // mm — retrait par côté au débouché : queue d'aronde qui
                      //      empêche le rail de se soulever dans l'alésage
guide_ep      = 4.5;  // mm — profondeur de l'encoche = épaisseur du rail au centre
guide_jeu     = 0.3;  // mm — jeu perpendiculaire du rail dans son encoche. Le rack
                      //      s'assemble avant vissage, le rail alignant lui-même les
                      //      plaques : les avant-trous se marquent à travers le rack monté
guide_entree  = 1.5;  // mm — chanfrein d'engagement au bout du rail (0 pour aucun)
guide_jeu_axe = 1.0;  // mm — raccourcissement du rail. Sans lui il ferait exactement
                      //      la longueur disponible et ne rentrerait pas
guide_talon   = 3;    // mm — hauteur du talon d'arrêt (0 pour aucun). Reculé d'une
                      //      profondeur de plaque, il porte contre la face ARRIÈRE de
                      //      la plaque avant et empêche le rail d'avancer et de sortir.
                      //      C'est une collerette LATÉRALE, posée au niveau du fond du
                      //      rail : plus large que l'encoche, elle ne peut pas la
                      //      traverser, et elle s'imprime sans le moindre porte-à-faux

// --- Bride de fixation ------------------------------------------------------

bride_ep     = 6;     // mm — épaisseur plaquée contre le bois
oreille      = 16;    // mm — débord latéral, seul endroit où loger une tête fraisée
vis_passage  = 5;     // mm — Ø de passage pour vis M4 (1 mm de flottement au Ø)
vis_tete     = 8;     // mm — Ø du fraisage. Tête fraisée M4 : 7,5 mm maxi (DIN 965),
                      //      donc la tête s'enfonce de 0,25 mm sous la surface

// --- Implantation (visualisation "montage" uniquement) ----------------------

ecart_plaques = 200;  // mm — entraxe recommandé entre les deux plaques
planche       = true; // false pour dégager la vue sur le rack
cylindres     = true; // false pour ne montrer que les pièces imprimées

// --- Grandeurs dérivées -----------------------------------------------------

alesage   = cyl_diametre + 2 * jeu_radial;
exterieur = alesage + 2 * paroi;
entraxe   = alesage + paroi;                        // les colliers se recoupent
largeur   = entraxe * (nb_cylindres - 1) + exterieur + 2 * oreille;
z_axe     = -exterieur / 2;
tete_prof = (vis_tete - vis_passage) / 2;           // fraisage à 90°

// Les vis ne peuvent aller que dans les oreilles : ailleurs, la tête serait noyée
// dans la matière des colliers.
vis_x     = [-(largeur / 2 - oreille / 2), largeur / 2 - oreille / 2];
vis_y     = plaque_prof / 2 - vis_tete / 2 - 2;

z_bas      = z_axe - alesage / 2;                   // point bas de l'alésage
z_encoche  = z_bas - guide_ep;                      // fond plat de l'encoche
z_bossage  = z_encoche - paroi;                     // dessous du bossage local
guide_long = ecart_plaques + plaque_prof - butee_ep - guide_jeu_axe;
// Position du rail dans le montage : crochet en appui sur la face avant, le jeu axial
// se retrouvant donc entièrement à l'arrière, contre la butée.
guide_y    = ecart_plaques / 2 + plaque_prof / 2 - guide_long / 2;

function axe_x(i) = (i - (nb_cylindres - 1) / 2) * entraxe;

// --- Profil de la plaque ----------------------------------------------------

// Colliers et bossages. La fermeture morphologique comble les cuspides où les
// cercles extérieurs se recoupent : elle n'ajoute que de la matière, jamais ne
// rogne les parois de 3 mm.
module profil_colliers() {
    offset(r = -conge) offset(r = conge)
        for (i = [0 : nb_cylindres - 1]) translate([axe_x(i), 0]) {
            translate([0, z_axe]) circle(d = exterieur);
            if (guide)
                translate([0, (z_axe + z_bossage) / 2])
                    square([guide_larg + 2 * paroi, z_axe - z_bossage], center = true);
        }
}

// Bride aux coins adoucis. La face supérieure reste plane pour porter à plat
// contre le bois.
module profil_bride() {
    r = min(coin, bride_ep / 2, largeur / 2);
    offset(r = r)
        translate([0, -bride_ep / 2])
            square([largeur - 2 * r, bride_ep - 2 * r], center = true);
}

module profil_plaque() {
    offset(r = -raccord) offset(r = raccord)
        union() {
            profil_colliers();
            profil_bride();
        }
}

// Profil de l'encoche : queue d'aronde à fond plat sous l'alésage, évasée vers le
// bas. Le rail en est la copie réduite du jeu, si bien que son dessus arqué
// prolonge exactement l'alésage tout en étant retenu en hauteur.
module profil_encoche() {
    h  = guide_ep + 2;                       // dépasse dans l'alésage, qui recoupe
    wb = guide_larg / 2;                     // demi-largeur en fond
    wh = guide_larg / 2 - guide_aronde;      // demi-largeur au débouché
    difference() {
        polygon([[-wb, z_encoche], [wb, z_encoche],
                 [wh, z_encoche + h], [-wh, z_encoche + h]]);
        translate([0, z_axe]) circle(d = alesage);
    }
}

// --- Volumes ----------------------------------------------------------------

// Extrusion dont les deux faces d'extrémité sont chanfreinées. Le profil étant
// très concave, ni hull() ni minkowski() ne conviennent : on empile des tranches
// de profil décalé. Avec une marche par couche d'impression, le résultat est
// exactement ce qu'un trancheur produirait d'un vrai chanfrein à 45°.
module extrude_chanfrein(h, c, n) {
    if (c <= 0) {
        translate([0, 0, -h / 2]) linear_extrude(height = h) children();
    } else {
        for (i = [0 : n]) {
            t = c * i / n;
            translate([0, 0, -h / 2 + c - t])
                linear_extrude(height = h - 2 * (c - t))
                    offset(delta = -t) children();
        }
    }
}

module corps_plaque() {
    // rotate([90,0,0]) conserve le sens vertical du profil et extrude selon Y.
    rotate([90, 0, 0])
        extrude_chanfrein(plaque_prof, chanf_bord, chanf_pas)
            profil_plaque();
}

// Alésages. Avec butée, ils s'arrêtent avant la face arrière (-Y).
module alesages(butee = false) {
    debut = butee ? -plaque_prof / 2 + butee_ep : -plaque_prof / 2 - EPS;
    fin   = plaque_prof / 2 + EPS;
    for (i = [0 : nb_cylindres - 1])
        translate([axe_x(i), debut, z_axe])
            rotate([-90, 0, 0])
                cylinder(h = fin - debut, d = alesage);
}
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

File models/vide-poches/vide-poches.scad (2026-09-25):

// vide-poches — panier mural suspendu sur deux chevilles d'assemblage,
// vis invisibles, crochet à casque intégré.
//
// Le panier s'enfile par le haut : on le présente au-dessus des deux vis, on le
// descend, il se verrouille. Rien à visser une fois la pièce en main, rien à
// démonter pour le décrocher.
//
// La fixation tient en trois canaux verticaux superposés dans l'épaisseur du dos,
// un par étage de la vis : le fût au fond, la tige lisse au milieu, la tête
// devant. Chacun monte dans le sien pendant la descente. Conséquence utile : la
// tête ne traverse jamais rien, elle monte dans son logement — donc aucun trou de
// passage n'est nécessaire et la peau avant reste pleine. Les vis sont invisibles
// de l'extérieur comme de l'intérieur du bac.
//
// La plaque porteuse occupe toute la longueur de tige lisse disponible : la tête
// vient buter directement contre elle, sans jeu axial vers l'avant.
//
// Le dos plaque à plat contre le bois sur toute sa surface. C'est lui qui encaisse
// le basculement, avec un long bras de levier — les vis ne travaillent qu'en
// cisaillement.
//
// FORME. Le bac n'est pas une boîte : il plonge à gauche, où les lunettes et la
// poche à tabac tiennent debout sur 91 mm, et remonte à droite, où les briquets et
// les câbles n'ont besoin que de 45. Entre les deux, un galbe et non une marche.
// Le crochet à casque passe sous la partie haute, de sorte que la masse pendante à
// gauche et le casque à droite se répondent.
//
// Cette forme est GRATUITE, et c'est ce qui la rend évidente : la pièce
// s'imprimant couchée sur son dos, le plan de la façade EST le plan du plateau.
// Toute silhouette qu'on y dessine sort sans un gramme de support. Ce qui coûte,
// c'est de faire varier la profondeur — et elle est constante ici. Tout le modèle
// est donc bâti sur un profil 2D en élévation, extrudé en profondeur.
//
// IMPRESSION : coque posée sur le dos, insert posé à plat. Aucun support.

include <../../lib/std.scad>
include <BOSL2/std.scad>

// "coque"   : dos + bac nu + crochet          — pièce à imprimer n°1
// "insert"  : le bac à séparations            — pièce à imprimer n°2
// "panier"  : les deux en place, pour regarder
// "gabarit" : réglet de perçage de la deuxième vis, et cale de réglage de sa
//             profondeur (consommable)
// "essai"   : les 10 derniers mm de la coque et de l'insert, côte à côte, pour
//             valider le jeu avant la vraie impression
// "montage" : le panier, le bois et les vis, pour vérifier la cinématique
PIECE = "panier";

// --- Chevilles de fixation ----------------------------------------------------
// Tout relevé au réglet sur la cheville en place. Ces cotes ne pilotent que
// l'épaisseur du dos, jamais le reste de la pièce.

// VIS COURTES. C'est le choix de vis qui commande l'épaisseur du dos, et donc
// tout le dessin. Avec la cheville d'origine — fût de 5,2 hors bois, tige lisse
// de 14, tête de 3 — il fallait 26,1 mm d'épaisseur, d'où des renflements de
// fixation massifs et un couloir large à réserver dans l'insert.
//
// Avec une vis dont la tige ne dépasse que de 2,5 mm plus une tête de 3, le dos
// tombe à 8,4. Les renflements deviennent des ondulations.
//
// Si la douille plastique reste en place et dépasse du bois, remettre sa saillie
// dans `col_h` : c'est un recul sec, ajouté à tout le reste.
col_d    = 7.3;   // mm — Ø du fût, si une douille dépasse encore
col_h    = 0;     // mm — de combien elle dépasse du bois. Zéro : vis directement
                  //      dans le bois, ou douille arasée.
// SPAX 3 × 12 à tête fraisée, relevée au pied à coulisse : tête Ø 6, tige Ø 3.
// Elle remplace une vis à tête cylindrique de Ø 8 × 3, et c'est la hauteur de
// tête qui compte : le cône s'enfonce dans la plaque au lieu de se poser devant.
vis_d    = 3.0;   // mm — Ø de la tige (filet compris)
vis_l    = 1.5;   // mm — tige LIBRE entre le bois et le départ du cône. C'est la
                  //      profondeur de vissage à respecter : la cale du gabarit
                  //      la donne.
tete_d   = 6.0;   // mm — Ø de la tête
tete_cone = (tete_d - vis_d) / 2;   // 1,5 — hauteur du cône, fraisure à 90°
tete_bord = 0.2;  // mm — petit bord cylindrique au-dessus du cône (estimé)
tete_h   = tete_cone + tete_bord;   // 1,7
jeu_cone = 0.3;   // mm — jeu entre le cône de la tête et le FRAISAGE de la plaque,
                  //      mesuré au rayon. Les deux surfaces étant à 45°, c'est
                  //      aussi le jeu axial : le panier avance de 0,3 mm, puis la
                  //      tête porte sur toute la surface conique.
                  //
                  //      Il a existé ici un simple « chanfrein » de 0,6 mm, censé
                  //      recevoir le cône. Il était bien à 45°, mais décalé de
                  //      0,5 mm au rayon : deux surfaces parallèles qui ne se
                  //      rencontraient JAMAIS. La tête n'appuyait qu'après avoir
                  //      avancé d'autant, et sur un anneau de 0,55 mm de large.
                  //      Mesuré en plaçant la vis dans le canal.

entraxe  = 124;   // mm — écartement des deux chevilles. La seconde est à poser,
                  //      donc cette valeur est libre : assez large pour empêcher
                  //      le vrillage, tout en laissant de la matière entre la
                  //      colonne de fixation et le bord de la pièce.
                  //      Il a valu 140, les renflements tout au bord. Mais il ne
                  //      restait alors que 7,5 mm entre le noyau et le flanc, et le
                  //      renflement y roulait à 70°. À 124, il reste 15,5 mm : il
                  //      s'y éteint à 37°. C'est ce qui le fait fondre dans la
                  //      plaque au lieu de s'y poser.

jeu_col  = 0.8;   // mm — jeu diamétral dans le canal du fût
jeu_vis  = 0.8;   // mm — jeu diamétral dans la fente de tige
jeu_tete = 2.0;   // mm — le logement de tête ne guide rien, il dégage. Il valait
                  //      3, calibré pour une tête de Ø 8 : sur une tête de Ø 6
                  //      c'était 1,5 mm de vide au rayon, qui gonflait le
                  //      renflement pour rien.
                  //
                  //      Il doit rester STRICTEMENT plus large que le trou
                  //      d'entrée (`jeu_entree`), qu'il prolonge en y. À égalité
                  //      leurs deux contours coïncident dans le plan qui les
                  //      sépare : 116 arêtes non-variété, mesurées.

// --- Dos ----------------------------------------------------------------------

fente_vis = vis_d + jeu_vis;                   // 3,8 — la fente qui porte
tete_bout = col_h + vis_l + tete_cone;         // 3,0 — fin du cône, Ø max de la tête

// LA PLAQUE PORTEUSE EST FRAISÉE, et mord donc DANS le cône : c'est ce qui la fait
// tenir sans jeu. Elle s'arrête `fraise_reste` avant la fin du cône, pour ne jamais
// buter sur le petit bord cylindrique qui le suit.
fraise_reste = 0.4;                            // mm
porteur  = tete_bout - fraise_reste;           // 2,6 — elle ne travaille qu'en
                                               // cisaillement sous le poids :
                                               // ~8,5 N sur 65 mm², soit 0,13 MPa.
// Départ du fraisage : là où le cône décalé du jeu atteint le rayon de la fente.
fraise_y0 = col_h + vis_l - vis_d / 2 + fente_vis / 2 - jeu_cone;   // 1,6

loge_e   = (tete_bout + tete_bord) - porteur + 0.4;   // 1,0 — la tête ne dépasse
                                               // plus que de 0,6 devant la plaque,
                                               // et 0,4 de jeu suffit. Il en avait
                                               // 1,7 pour 1,2 de tête : 0,5 de vide.
dos_av   = 1.2;                                // peau avant, celle qui cache tout :
                                               // trois passes de buse de 0,4. Elle ne
                                               // porte rien, elle ferme le logement —
                                               // un pontage de 7,5 mm à l'impression.
dos_e    = col_h + porteur + loge_e + dos_av;  // 4,8 — 5,3 avant le fraisage, 7,6
                                               // avec l'ancienne vis à tête cylindrique
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

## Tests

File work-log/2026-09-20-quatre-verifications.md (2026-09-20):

# Quatre vérifications, pas une

*Journal de conception — 20 septembre 2026*

Une journée passée à concevoir une pièce imprimable en 3D avec un assistant, et ce
qu'elle apprend sur la répartition du travail entre une machine qui calcule vite et un
humain qui a déjà manipulé des objets.

L'objet : un rack à visser sous une planche en bois, pour ranger deux cylindres de CO2 à
l'horizontale, invisibles depuis le dessus.

Précision qui a son importance pour les cotes : il s'agit de **cylindres universels**
425 g au filetage TR21×4, pas de cylindres de marque — ils se rechargent chez n'importe
quel distributeur de gaz. L'appareil est une gazéifieuse **Aarke**, qui accepte ce
filetage ; ne pas passer par du matériel SodaStream est un choix assumé, pour des raisons
géopolitiques. Les deux familles de cylindres n'ont d'ailleurs pas les mêmes dimensions,
et c'est la première chose qu'il a fallu trancher.

---

## Le piège nommé dès la première minute

La demande initiale contenait déjà l'avertissement :

> Le piège facile serait d'avoir finalement que des demi-cercles sous la planche en bois,
> ce qui ne permettrait pas de faire entrer un cylindre SodaStream.

C'est exactement le genre de chose qu'on ne trouve pas en raisonnant sur des cotes. Une
gouttière semi-circulaire vissée sous une planche est géométriquement irréprochable, et
la bouteille tombe. Il fallait des alésages **fermés à 360°**, donc une insertion axiale,
donc un rail de guidage, donc une queue d'aronde pour le retenir, donc un talon d'arrêt
qui ne gêne ni le cylindre ni l'impression.

Chacune de ces implications a été découverte au fil de la journée, et presque toujours de
la même façon : par une question de l'humain, jamais par une vérification de la machine.

## La thèse

**L'assistant était bon pour vérifier, mauvais pour savoir quoi vérifier.**

Les idées de conception — le rail de guidage, la queue d'aronde, le talon reculé — sont
venues de l'humain. Et surtout, **chaque défaut de conception a été attrapé par une de
ses questions** :

| La question | Le défaut qu'elle a révélé |
|---|---|
| « le rail sera juste posé, il va beaucoup bouger » | rien ne le retenait vers le haut |
| « assure-toi que l'aronde ne soit pas trop fine » | le talon de la lèvre méritait 1 mm de plus |
| « je ne comprends pas comment ce crochet bloque quoi que ce soit » | il bloquait la mauvaise direction |
| « cette butée va compliquer l'impression » | elle exigeait des supports sur 236 mm |
| « assure-toi qu'il y ait assez de polygones » | le passage réel n'est pas le diamètre nominal |

Ces questions ont un point commun : elles viennent d'avoir tenu des objets dans les
mains. Savoir qu'une pièce mal tenue cliquette, qu'une languette fine de PLA casse, qu'un
porte-à-faux veut du support, qu'on emboîte avant de visser. Aucune ne demandait de
savoir modéliser.

Ce que la machine apportait en face, c'était le calcul qui transforme une intuition en
décision :

- « ça peut être difficile de bien viser » devient **±50 mm de dérive** au second collier.
  Une fois le cylindre engagé dans les 12 mm du premier alésage, il peut basculer de 14° ;
  200 mm plus loin, le nez a dérivé de 50 mm. Le rail n'est plus une commodité, il est
  nécessaire.
- « pas trop fine » devient **+113 % de rigidité pour 1 mm de hauteur** : la rigidité en
  flexion varie comme le cube de l'épaisseur, passer le rail de 3,5 à 4,5 mm la double.
- « assez de polygones » devient **0,0218 mm de perte pour 2,978 mm de jeu**, soit un
  rapport de 137.

## Quatre vérifications, pas une

Le cœur de ce qu'on a appris tient là. Une pièce peut être juste sur un axe et fausse sur
un autre. Quatre contrôles indépendants ont chacun rattrapé, dans cette seule journée, un
défaut qu'**aucun des trois autres ne voyait**.

### Les sections

Épaisseurs, jeux, matière restante aux emboîtements. Se mesurent sur le maillage exporté.

C'est ici qu'on rencontre le piège le plus élégant de la journée. OpenSCAD trace des
polygones **inscrits** : les cordes passent à l'intérieur du cercle nominal, donc un
alésage sort toujours plus petit que sa cote. Sur le rack :

```
Diamètre circonscrit, par les sommets  : 63,0001 mm
Diamètre inscrit, par les cordes       : 62,9783 mm   ← le passage réel
```

Un contrôle naïf sur les sommets affiche 63,0001 et **masque exactement le défaut qu'on
cherchait**. C'est la distance du centre au milieu de chaque corde qu'il faut mesurer.

Ici la perte est négligeable — 0,022 mm pour 2,98 mm de jeu — mais c'est la méthode qui
compte, pas le verdict.

### La cinématique

*Dans quel sens cette pièce peut-elle bouger, et qu'est-ce qui l'en empêche ?*

Le rail de guidage portait un crochet censé l'empêcher de sortir. Trois vérifications
successives avaient mesuré ses sections, son jeu, sa matière. Aucune n'avait posé cette
question. Quand elle l'a été, l'analyse a pris trois lignes :

> Le crochet est en y = 120, la face avant de la plaque en y = 120. Si le rail recule, le
> crochet appuie contre elle : bloqué. S'il **avance**, le crochet s'éloigne et le rail
> sort librement.

Le crochet était donc à la fois **redondant** — le recul était déjà limité à 1 mm par la
butée du fond — et **inutile pour la seule direction qui comptait**. La correction : le
reculer de 40 mm, exactement la profondeur d'une plaque, pour qu'il porte contre sa face
*arrière*.

Les sections ne voient jamais ce genre de chose.

### L'imprimabilité

Porte-à-faux, pontages, orientation des couches vis-à-vis de la charge.

Et c'est là que la correction précédente a créé un défaut nouveau. Le talon reculé
descendait de 5 mm sous le fond du rail — or le rail s'imprime précisément **posé sur ce
fond**. Il aurait fallu surélever 236 mm de pièce sur support. La consigne « aucun
support » écrite trois messages plus tôt était devenue fausse.

La correction tient en une idée : rien n'oblige un talon à descendre. Il ne doit pas
traverser l'encoche, et pour ça il suffit qu'il soit **plus large** qu'elle. Il s'évase
donc latéralement, à partir du même fond plat.

| | avant | après |
|---|---|---|
| Encombrement | 19,4 × 236 × 10,07 mm | **26,0 × 236 × 4,77 mm** |
| Matière sous le fond | oui | **non** |
| Supports | sur 236 mm | **aucun** |

**Leçon générale : une modification de forme peut invalider une contrainte de fabrication
établie plus tôt.** C'est une régression qu'aucune mesure de section ne détecte, et il
faut la revérifier explicitement après chaque changement de géométrie.

### La fraîcheur

Les sorties viennent-elles bien du source actuel ?

Une génération lancée en tâche de fond continue de tourner pendant qu'on modifie le
fichier. Les rendus se retrouvent alors issus de versions différentes, sans que rien ne
le signale. Une vue d'ensemble avec **plus d'une heure de retard** sur son source a ainsi
été publiée dans l'aperçu partagé.

D'où un garde-fou ajouté dans la foulée : chaque sortie produite est inscrite dans un
manifeste avec l'empreinte SHA-256 des sources dont elle vient — le fichier du modèle
*et* la bibliothèque partagée, puisqu'un module commun périme aussi les rendus.

```bash
python scripts/scad.py check <slug>
```

sort en code 1 et nomme les fichiers fautifs. L'outil de publication refuse de partir
tant qu'il en reste un.

## Le vrai adversaire : les pannes silencieuses

Un fil traverse toute la journée : **rien n'a jamais levé d'erreur.**

La bride de fixation a purement et simplement disparu d'un modèle qui compilait sans un
mot. En cause, un arrondi de coin trop grand pour la pièce : `6 − 2×4` fait −2, et
OpenSCAD accepte sans broncher un carré de hauteur négative. Profil vide, aucune erreur,
deux colliers flottant dans le vide sur le rendu.

Rien ne l'aurait attrapé, sinon **regarder l'image**.

Autres pannes muettes de la même journée :

- Un `$fa = 1` produisant 360 segments sur un alésage de Ø 69 et portant un rendu à plus
  de sept minutes. À `$fa = 3`, la flèche tombe à 0,011 mm — très en deçà de ce qu'une
  buse de 0,4 mm reproduit — et le rendu à moins de deux.
- Un `cmp` criant « différent » sur deux géométries rigoureusement identiques, parce
  qu'il opposait un export binaire à un export ASCII. Il fallait comparer le nombre de
  triangles (51 600 de part et d'autre), de sommets distincts et l'encombrement.
- Une tête de vis annoncée de mémoire à 8,4 mm, alors que la norme DIN 965 donne
  **7,5 mm maximum** pour du M4.

## Pourquoi ça a mieux marché qu'un script copié-collé

Le workflow précédent de l'auteur : demander un script OpenSCAD à un modèle, le coller
dans un playground en ligne, regarder, décrire ce qui cloche. Résultat jugé « assez
médiocre ».

Trois explications possibles, classées par la quantité de preuves que cette journée
apporte.

**1. La boucle s'est fermée.** De loin la mieux étayée. Dans le workflow copier-coller,
le modèle ne voit jamais le résultat. Ici, trois canaux de retour distincts ont fonctionné,
et chacun a attrapé ce que les deux autres ne voyaient pas :

- **exécuter** le code → l'explosion du temps de calcul, l'export en ASCII
- **regarder** les images → la bride évaporée
- **mesurer** le maillage → le diamètre inscrit, l'identité des plaques, la hauteur du talon

**2. L'humain était dans la boucle**, avec une intuition physique. Indépendant du modèle.

**3. La capacité brute du modèle.** Plausible, invérifiable ici. Ce qu'on observe : les
raisonnements décisifs — la dérive de ±50 mm, la distinction inscrit/circonscrit, le sens
de l'aronde — sont de l'arithmétique et de la géométrie élémentaires. Les erreurs commises
n'étaient pas des échecs de raisonnement mais **des échecs d'attention** : oublier de
revérifier une contrainte posée trois messages plus tôt. Ça penche pour l'outillage
plutôt que pour le modèle.

### Une nuance qui compte

On dit volontiers « le résultat est validé s'il correspond au prompt ». Ce n'est pas ce
qui s'est passé, et la distinction est importante.

Le prompt était satisfait **par la toute première version** — celle dont la bride avait
disparu. Ce qui a validé le résultat, ce sont des **mesures** et le **jugement de
l'humain**. Un assistant qui s'autovalide contre sa propre compréhension de la demande
tourne en rond.

## Ce qui reste

Le rack coûte trois euros de PLA. Ce qui a de la valeur, c'est ce qui se transporte au
modèle suivant — 1 605 lignes, sans une seule référence à cette pièce précise :

| | lignes | rôle |
|---|---|---|
| le pilote OpenSCAD | 428 | rendus, coupes, tranches, dessins, STL, encombrement, péremption |
| l'aperçu web | 619 | viewer 3D et planche de rendus, publiables |
| les conventions et la méthode | 333 | ce document et ses règles |
| les modules de coupe, l'installation des libs | 127 | |

Mais **le vrai mécanisme de réutilisation est le fichier d'instructions du dépôt.** Chaque
leçon de la journée y est écrite, et il est réinjecté au début de chaque session. Le
prochain modèle démarre donc avec les quatre vérifications, l'obligation de regarder les
rendus, les bornes de paramètres déjà payées. Ce n'est pas la mémoire de l'assistant qui
porte l'apprentissage — c'est le dépôt. C'est ce qui rend l'exercice cumulatif au lieu
d'être un coup unique.

Un mot sur l'outillage local face à un playground en ligne : le playground donne un
visualiseur, il ne donne pas de quoi **mesurer**. Tout le contrôle décrit ici repose sur
la possibilité de relire le STL exporté et d'en compter les triangles, d'en calculer un
diamètre inscrit, de vérifier qu'aucune matière ne descend sous le plan d'impression.

## L'honnêteté finale

**Rien n'a encore été imprimé au moment d'écrire ces lignes.**

Une plaque était en cours sur le plateau, les deux autres pièces attendaient. Tout ce qui
précède a été vérifié sur des maillages, jamais sur du plastique. Le jeu de 0,3 mm de la
queue d'aronde est peut-être trop serré ; le talon casse peut-être au montage ; le
cylindre entre peut-être moins bien que les 2,978 mm calculés ne le laissent croire.

C'est la cinquième vérification, et c'est la seule qu'aucun outil ne remplace.

---

*Le dépôt : [github.com/salfab/3d-printing-models](https://github.com/salfab/3d-printing-models)*

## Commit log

2026-09-20 Socle du dépôt et rack à cylindres SodaStream
    Conventions : un modèle par sous-répertoire sous models/, chaque .scad
    exposant un module main(), unités en millimètres.
    Outillage :
    - scripts/scad.py pilote OpenSCAD — rendus 3D, coupes, tranches, dessins
    techniques, export STL et encombrement lu dans le maillage. Il ajoute
    vendor/ à OPENSCADPATH.
    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
    [_template.scad, rack-sodastream.scad]
2026-09-20 README par modèle : convention, squelette, et README racine
    Le README d'un modèle fait partie du modèle. CLAUDE.md en fixe désormais les
    sept sections attendues, dont deux qui manquaient le plus souvent : les bornes
    des paramètres et ce qui casse au-delà, et ce qui reste à vérifier.
    models/_template/README.md fournit le squelette à copier avec le .scad.
    Ajoute aussi un README racine, qui manquait au dépôt : liste des modèles,
    installation, et les commandes de l'outillage.
2026-09-20 Rail : talon latéral au lieu d'un talon descendant
    Le talon descendait de 5 mm sous le fond du rail, qui s'imprime posé sur ce
    fond : il aurait fallu surélever les 236 mm de la pièce sur support. La
    consigne « aucun support » du README était devenue fausse.
    Il s'évase désormais latéralement depuis le même fond plat, sur 26 mm de large
    contre une encoche de 20 : il ne peut toujours pas la traverser et porte sur le
    bossage par 4 mm de chaque côté, mais toute la face inférieure touche le
    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
    [rack-sodastream.scad]
2026-09-20 Détecte les sorties périmées avant publication
    scripts/scad.py inscrit chaque sortie produite dans out/.manifest.json avec
    l'empreinte SHA-256 des sources dont elle vient — le .scad du modèle et lib/,
    puisqu'un module partagé périme aussi les rendus.
    Ajoute la commande `check`, qui nomme les sorties issues d'un autre source et
    sort en code 1. preview_pack.py refuse désormais de publier tant qu'il en
    reste, avec --ignorer-peremption comme échappatoire explicite.
    Le cas se produit réellement : une génération lancée en tâche de fond continue
    pendant qu'on modifie le .scad, et les sorties se retrouvent issues de versions
    différentes sans que rien ne le signale. Une vue périmé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
2026-09-20 Ø du cylindre confirmé au pied à coulisse
    Les 60 mm venaient de fiches produit contradictoires — c'était la seule cote du
    projet jamais vérifiée, et elle pilote alésage, entraxe, largeur des plaques et
    rail. Mesure faite : 60 mm. Aucune géométrie ne change.
    Le README distingue désormais ce qui est mesuré de ce qui est relevé : la
    longueur de 356 mm vient encore d'une fiche, mais ne conditionne aucune cote
    des pièces imprimées.
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2026-09-20 Rend le modèle visible depuis le README sur GitHub
    Un viewer Three.js ne peut pas être embarqué dans un README : GitHub retire
    tout JavaScript du markdown rendu. En revanche il affiche nativement les
    fichiers .stl dans un viewer 3D interactif, jusqu'à 10 Mo.
    Versionne donc les trois STL livrables dans models/rack-sodastream/stl/, avec
    une exception au .gitignore, et les lie depuis le README. Ajoute quatre rendus
    dans doc/ : l'ensemble monté, la plaque avant, le rail et la coupe
    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
    [rack-sodastream-arriere.stl, rack-sodastream-avant.stl, rack-sodastream-guide.stl]
2026-09-20 Illustrations : le rail visible, les bouteilles reconnaissables
    La vue d'ensemble laissait croire qu'on imprimait de gros tubes, et aucune image
    ne montrait le rail de guidage. Trois changements.
    Le cylindre de visualisation reçoit un robinet — épaulement, col fileté,
    collerette hexagonale, tige. Il devient reconnaissable à sa seule silhouette,
    ce qui compte puisque le rendu CGAL ignore color().
    Ajoute une vue de dessous quasi verticale et un paramètre `cylindres` pour
    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
    [rack-sodastream.scad]
2026-09-21 Illustrations refaites, et deux modifications inutiles annulées
    Une image monochrome où les bouteilles ont la couleur des pièces n'apprend
    rien, et le rendu couleur d'OpenSCAD 2021.01 n'est pas fiable sur ce modèle :
    color() est ignoré en CGAL, et l'aperçu OpenCSG fabrique des traînées blanches
    qu'on prend pour des trous. La vue de dessous montre donc le rack seul.
    Trois mesures sur les maillages écartent le soupçon de trou : la surface de
    l'alésage s'arrête à -3,00 mm, aucun sommet n'existe à z = 0 près des axes, et
    la face de butée arrière ne contient aucun sommet dans le cercle d'alésage.
    Corrige le culot de la bouteille de visualisation, dont le cône partant de
    Ø 50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
    [rack-sodastream-arriere.stl, rack-sodastream-avant.stl, rack-sodastream.scad]
2026-09-22 vide-poches : panier mural à vis invisibles, crochet à casque intégré
    Le panier s'enfile par le haut sur deux chevilles d'assemblage. Trois canaux
    verticaux superposés dans l'épaisseur du dos, un par étage de la vis :
    collerette au fond, tige lisse au milieu, tête devant. La tête ne traverse
    jamais rien, elle monte dans son logement — donc aucun trou de passage, et la
    peau avant reste pleine.
    Imprimable d'un seul bloc, posé sur le dos : tout ce qui pointe vers l'avant à
    l'usage devient vertical sur le plateau, y compris le bras du crochet. Aucun
    support.
    Deux défauts trouvés à la coupe et corrigés : la grille d'allègement ne laissait
    que 1,5 mm de matière sur le pourtour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
    [vide-poches.scad]
2026-09-22 vide-poches : coque et insert de séparation en deux pièces
    Les séparateurs deviennent un insert amovible. Il n'a pas de fond — c'est celui
    de la coque qui sert — donc il n'ajoute rien au poids, et en retire même 20 g
    puisqu'il est rétréci au pourtour. Changer d'agencement ne coûte plus que 53 g
    de réimpression au lieu de 435, et la coque reste utilisable en plateau nu.
    Coque et insert se déduisent de la même liste `cuves` : elles ne peuvent pas
    diverger.
    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
    [vide-poches.scad]
2026-09-22 vide-poches : l'insert porte son propre fond
    Le peigne sans fond économisait 29 g contre quatre parois de 2,4 mm hautes de
    57, en porte-à-faux jusqu'à 97 mm, ne touchant le plateau que par leur tranche :
    7 cm² pour toute la pièce. Avec son fond, l'insert colle sur 145 cm², tient tout
    seul et se sort plein.
    Le fond de la coque n'est pas supprimé pour compenser : c'est lui qui relie la
    paroi avant au dos sur 200 mm de portée.
    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
    [vide-poches.scad]
2026-09-22 vide-poches : cotes de cheville relevees au reglet
    Fut 6 mm, tige lisse libre 14 mm, tete 3 mm de haut. La plaque porteuse passe
    de 13 a 13,5 et le dos de 23,9 a 26,9 ; la profondeur hors tout suit, 105,3.
    Le diametre de tete reste non mesure et volontairement majore a 8 : son
    logement ne guide rien, l'elargir ne coute rien.
    Empilage verifie sur le maillage : 0 / 1,60 / 6,00 / 19,50 / 24,50 / 26,90.
    [vide-poches.scad]
2026-09-22 vide-poches : la saillie du fut se deduit de la cote prise en place
    22,2 mm hors bois vis montee, moins 14 de tige et 3 de tete, donnent 5,2 mm de
    fut apparent la ou il en mesure 6 hors du bois : 0,8 mm sont enfouis.
    A col_h = 6 la plaque porteuse allait de 6 a 19,5 alors que le dessous de tete
    est a 19,2. Elles se chevauchaient de 0,3 mm : la tete aurait tape la plaque
    avant que le dos ne touche le bois, et le panier serait reste decolle, en appui
    sur deux tetes de vis. Le degagement prevu de 0,5 mm est retabli.
    La cote prise sur l'ensemble monte fait desormais reference, les autres en
    decoulent.
    Fixation arretee : deux chevilles a la meme hauteur, entraxe 140. La douille
    metallique exis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
    [vide-poches.scad]
2026-09-22 vide-poches : rangement debout, et la hauteur des lunettes pilote bac_h
    Lunettes et poche a tabac ranges sur leur petit cote : leurs empreintes passent
    de 150x46 a 50x37 et de 105x30 a 85x30. La largeur de la piece tombe de 200 a
    135, l'entraxe des chevilles de 140 a 95.
    En echange ils depassent du bord, d'ou la contrainte inverse : le haut des
    lunettes doit rester a moins de 35 mm au-dessus de l'axe des colonnettes.
    Debout elles font 145 et posent sur le fond de l'insert, donc
    depassement = 145 - (bac_h - fond - insert_fond) - garde_vis
    Cette inegalite, et non un besoin de volume, fixe bac_h a 95. On est a 34 mm.
    Un bac de 95 serait un puits ou pecher un briquet : chaque cuve porte
    de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
    [vide-poches.scad]
2026-09-22 vide-poches : appui des fonds releves
    Un fond releve dans un compartiment exterieur ne reposait que sur ses bords
    interieurs : les bords exterieurs sont fermes par la coque, pas par l'insert.
    A l'impression c'etait un pontage accroche par deux bords adjacents seulement,
    qui se serait affaisse.
    Le rebord de l'insert monte desormais jusqu'a eux. Uniquement au droit des
    compartiments concernes : sur tout le pourtour cela couterait 40 g, sur les
    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
    [vide-poches.scad]
2026-09-22 vide-poches : fond a deux niveaux, silhouette galbee, -76 g
    Le bac n'est plus une boite. Il plonge a gauche, ou lunettes et tabac tiennent
    debout sur 91 mm, et remonte a droite, ou briquets et cables n'ont besoin que
    de 45. Entre les deux un galbe, et le crochet a casque sous la partie haute.
    Cette forme est gratuite : la piece s'imprimant couchee sur son dos, le plan de
    la facade EST le plan du plateau. Toute silhouette qu'on y dessine sort sans un
    gramme de support ; ce qui coute, c'est de faire varier la profondeur, et elle
    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
    [vide-poches.scad]
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2026-09-22 vide-poches : vrai trou de serrure, dos mince, galbe avant debride
    La tete entre desormais par un TROU perce dans la plaque porteuse, au bas de la
    course. Avant, elle remontait depuis le bord inferieur de la piece, ce qui
    obligeait les 26 mm d'epaisseur de fixation a courir sur 145 mm de haut. Il
    suffit maintenant de 40 mm de bossage ; le reste du dos est une plaque de 3 mm.
    Consequences : 23 mm liberes derriere le bac deviennent du rangement, la piece
    perd 15 mm de profondeur hors tout tout en gagnant 8 mm de rangement, et la
    coque tombe de 607 a 225 cm3.
    Les cavites sont desormais DECOUPEES dans l'enveloppe interieure de la coque, au
    lieu d'etre posees a un niveau. Le dessous de la coque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
    [vide-poches.scad]
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2026-09-22 vide-poches : cavites hoistees, renflements progressifs, coins tenus
    Le crochet ressortait DANS un compartiment : sa racine est noyee de 15 mm dans
    la coque, le fond du bac peu profond est 2,4 mm plus haut, et le bac faisait sa
    soustraction dans son coin -- rien ne taillait le crochet. Les cavites sont
    desormais retirees au niveau de la COQUE. Toute piece qui vient se noyer dedans
    est creusee par les memes cavites. 23 cm3 de matiere en moins, qui etaient dans
    le rangement.
    Les bossages de fixation etaient deux plaques posees sur l'arche, avec une arete
    franche tout autour. C'est maintenant un renflement : l'epaisseur du dos passe de
    3 mm au bord a 26 au droit des vis, par une lentille dont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
    [vide-poches.scad]
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2026-09-22 vide-poches : vis courtes, le dos passe de 26 a 8 mm
    C'est le choix de vis qui commandait l'epaisseur du dos, et donc tout le dessin.
    Avec la cheville d'origine -- fut de 5,2 hors bois, tige lisse de 14, tete de 3 --
    il fallait 26,1 mm, d'ou des renflements de fixation massifs, une casquette
    au-dessus du bac et un large couloir a reserver dans l'insert.
    Avec une vis dont la tige ne depasse que de 2,5 mm plus une tete de 3 :
    0 + 2,0 + 4,0 + 2,4 = 8,4 mm
    Les renflements deviennent des ondulations. La plaque porteuse tombe a 2 mm et ne
    travaille qu'en cisaillement sous le poids : 8,5 N sur 50 mm2, soit 0,17 MPa.
    Creux entre les epaules remonte de 102 a 120 : la ligne du dessus redevient
    c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
    [vide-poches.scad]
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2026-09-23 vide-poches : le rayon d'arrondi avant borne par l'epaisseur
    Defaut silencieux trouve par l'utilisateur : les renflements de fixation ne
    couvraient pas les trous de serrure, donc ne servaient a rien.
    Cause. r_av_dos valait 10 mm, regle quand le dos faisait 26 mm d'epaisseur. Le
    dos n'en fait plus que 9,4. Dans extrude_arrondi, le corps etait alors extrude
    sur e - r = -0,6 mm, et les tranches suivantes rognees de jusqu'a 10 mm. Le noyau
    du renflement fait 20 mm de diametre : un retrait de 10 l'annule exactement. Le
    renflement existait donc partout SAUF a son sommet, la ou passe le trou de
    serrure. Aucune erreur a la compilation.
    extrude_arrondi borne desormais le rayon a e - 0,6 par constru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
    [vide-poches.scad]
2026-09-23 vide-poches : coque balayee par BOSL2, et trois defauts de fixation
    BOSL2 sur la COQUE SEULE, comme suggere : bac_plein, cavites, dos et bossages
    passent par offset_sweep, le bornage de l'insert reste sur l'extrusion en
    tranches. C'est lui qui avait fait exploser l'insert a 1708 cm3 et planter CGAL
    sur le test de descente ; il n'a besoin que d'etre conservateur, et le jeu de
    0,5 mm absorbe l'ecart entre les deux methodes. Les contours deviennent des
    chemins de points, echantillonnes SEULEMENT la ou la courbe le demande :
    round_corners refuse un conge plus large que la place entre deux sommets.
    Trois defauts de fixation trouves en verifiant, tous silencieux :
    1. dos_ep valait 3,0 pour une t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
    [vide-poches.scad]
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2026-09-24 vide-poches : les renflements de fixation deviennent la plaque qui gonfle
    Les renflements autour des vis se lisaient comme deux domes poses sur la
    plaque, avec un angle franc a la jonction. La cause etait dans le profil : une
    lentille empilee dont le rayon suivait boss_etale * cos(90*i/n). Tangente a sa
    crete, mais VERTICALE a sa base — la derivee du cosinus est nulle en zero, le
    contour ne retrecissait presque pas en quittant la plaque, la paroi en partait
    donc a 90 degres. Un quart d'ellipse.
    Le profil est maintenant un S quintique : a une distance rho au-dela du noyau,
    la surepaisseur vaut (dos_e - dos_ep) * liss5(1 - rho/boss_etale). Derivees
    premiere ET seconde nulles aux deux bouts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
    [vide-poches.scad]
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2026-09-24 vide-poches : la fixation descend dans le bac, la casquette devient nette
    Poses sur la plaque au-dessus de l'arase, les renflements se voyaient
    toujours, quelle que soit leur forme — cinq versions l'ont montre. Ils vivent
    desormais sous l'arase, sur la paroi arriere des compartiments, ou les objets
    les cachent. La casquette n'est plus qu'une plaque nette, purement decorative.
    L'axe des vis se deduit maintenant de l'arase, par le haut :
    z_vis = z_haut - arase_marge - boss_Dhaut - boss_haut = 78, au lieu de 115.
    boss_haut passe de 12 a 9, boss_etale de 30 a 12 (dans le bac, tout ce qu'il
    etale est pris sur les compartiments). Le renflement s'eteint, tangent, avant
    la paroi laterale du bac,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
    [vide-poches.scad]
2026-09-24 vide-poches : sans casquette, insert en petit bac, et un conge sous le crochet
    La casquette disparait. La fixation etant descendue dans le bac, elle ne
    portait plus rien : le dos prend exactement la silhouette du bac, et le bord
    est au meme niveau sur tout le pourtour, avec les memes conges. La plaque du
    dos devient une extrusion droite — son ancien arrondi avant creusait une
    rainure de 1,4 mm partout ou son contour rejoignait celui du bac.
    L'insert devient un petit bac qui cache les renflements : sa paroi arriere
    passe DEVANT eux, a dos_e + jeu = 8,1 mm du mur, et ses compartiments arriere
    commencent une paroi plus loin (yi0_ins = 10,1). Plus aucun couloir taille
    dans l'insert. Il reste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
    [vide-poches.scad]
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2026-09-24 vide-poches : les inserts portent le lisere du bord et ferment la fente arriere
    Parois d'insert pleine hauteur (1,2 mm), rognees par l'enveloppe exterieure
    de la coque : leur dessus prolonge les arrondis du bord, en deux couleurs.
    Un bandeau arriere couvre la fente au-dessus des renflements, porte par un
    encorbellement jamais plus plat que 45 degres. Coque inchangee de dessin,
    elargie a 182 et approfondie a 85,8 pour garder les compartiments.
    Test de descente refait par niveaux.
    [vide-poches.scad]
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2026-09-24 vide-poches : vis SPAX a tete fraisee, jeu 0,3, fond qui suit le galbe, piece d'essai
    - SPAX 3x12 : fente chanfreinee a 45 degres ou le cone porte en siege ;
    dos_e 7,6 -> 5,3, bosses de 18 mm ; cale de profondeur au gabarit.
    - insert_jeu 0,5 -> 0,3 ; larg 181, bac_int 80,5 (fixe par le crochet).
    - plancher() : le fond suit le dessous de la coque, galbe compris, pour la
    coque et l'insert ; plus de niveaux de fond codes. L'insert peu profond
    demande des supports sous le fond, et lui seul.
    - PIECE=essai : les 10 derniers mm de la coque et des inserts.
    [vide-poches.scad]
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2026-09-24 vide-poches : le conge du crochet se place par son centre, plus d'oscillation
    Les iterations qui resolvaient la distance au flanc oscillaient pres du bord
    - sauts de pente de 6 par dixieme de millimetre - et ces oscillations se
    lisaient comme des fissures le long du dessous du bras.
    Le conge est desormais le cercle de rayon croc_rb tangent aux deux faces : on
    resout pour son centre. Exact pour un flanc droit, sans iteration, sauts de
    pente sous 0,11. Il est plafonne a sa valeur au point de tangence, au-dela de
    quoi le cercle repasserait devant le flanc.
    [vide-poches.scad]
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2026-09-25 vide-poches : un vrai fraisage pour la tete conique, et 0,5 mm gagnes
    Le chanfrein de 0,6 mm etait bien a 45 degres comme le cone, mais decale de
    0,5 mm au rayon : deux surfaces paralleles qui ne se rencontraient jamais. La
    tete n'appuyait qu'apres que le panier ait avance d'autant, et sur un anneau de
    0,55 mm. Mesure en placant la vis dans le canal.
    La plaque est desormais fraisee au cone lui-meme, avec 0,3 mm de jeu : elle y
    mord 1,0 mm et la tete porte sur 19 mm2 en se centrant. Elle passe de 2,0 a
    2,6 mm, mais deux vides sont repris en meme temps : jeu_tete de 3 a 2 (le
    logement datait de la tete de 8) et dos_av de 1,6 a 1,2. dos_e tombe de 5,3 a
    4,8 et les bosses de 12 a 11 mm de large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
    [vide-poches.scad]
2026-09-25 vide-poches : le gabarit porte un echantillon de serrure
    Un morceau du vrai dos, 24 x 30, rattache au reglet par deux ponts qu'on casse :
    renflement, fente, trou d'entree, fraisage, logement et peau. C'est dos() qu'on
    y decoupe, donc toute correction s'y retrouve, et il s'imprime dans la meme
    orientation que la coque — le pontage de la peau y est representatif.
    Enfile sur une vis reglee, il verifie la course, le siege de la tete et la peau
    avant d'engager 320 cm3 de panier.
    [vide-poches.scad]
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
